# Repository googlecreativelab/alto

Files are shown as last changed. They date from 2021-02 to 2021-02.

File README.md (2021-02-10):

# Alto - a little teachable object<br>
<br>

Say hello to Alto, a little teachable object! Alto is designed to demonstrate the most basic aspects of machine learning (ML) by building a machine you can teach yourself. Alto uses the [Coral USB Accelerator](https://coral.ai/products/accelerator/) and Raspberry Pi to help show how you can easily add machine learning to your next hardware project.

This repository contains all of the instructions and files required to build an Alto of your own from scratch. Best of all, Alto is completely open source! Anyone can fork the code, schematics, and case designs to create a little teachable object of their own.

To find out more about what else you can do with the Edge TPU in the USB Accelerator, and get inspiration for your own projects, head to [Coral's Examples page](https://coral.ai/examples/).

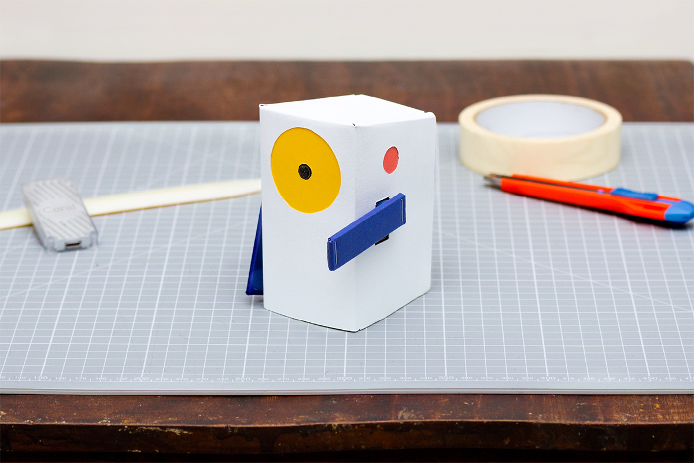
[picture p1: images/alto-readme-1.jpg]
alto hero image

<br>
<br>
## What you’ll find in this document

This document has five chapters:

-  **[User guide](#User-guide)** -
Explaining Alto’s interface and the ways Alto can be used.

-  **[Make your own Alto](#Make-your-own-Alto)** -
A visual guide to constructing your own Alto, covering setting up the software, soldering your circuitry and constructing Alto’s cardboard body.

- **[Experiment with Alto](#Experiment-with-Alto)** -
A set of simple experiments to help understand how Alto works, and how you can use Alto to introduce some of the basic concepts of machine learning to others.

- **[Remixing Alto](#Remixing-Alto-for-your-projects)** -
A brief introduction to how you can hack your Alto to look and behave differently to fit your own application.

- **[Technical overview](#Technical-Overview)** -
A more detailed overview of Alto’s software and electronics and how they function.<br>
<br>

## User guide

### Machine learning at its simplest

Alto has a camera on its front, and an arm and button on each side. Alto uses the camera to observe the world around it. The buttons are used to start learning, and Alto will point with its arm when it sees something it has learned to recognise. 

about alto animated gif<br>
<br>

Alto can learn two classes of things. When Alto recognises one of them, it will point with its corresponding arm. Alto demonstrates machine learning at its most basic level: what you teach it to recognise is up to you!

alto points at fruit<br>
<br>

### Teaching Alto

To teach Alto to recognise an object, place the object in front of it, and press one of the buttons on the side. As Alto takes images to learn about the object, its arm will slowly raise. When Alto’s arm is stretched out horizontally, the learning process has finished. Now, when the same object is placed in front of it, Alto will point at the object.

The more you teach Alto about the same object, the better it will become at recognising that thing. You can teach Alto as many times as you like! Try teaching Alto more about an object by rotating the object to show different angles and place it at various distances, pressing the same button each time.

It's important to try and balance the amount of learning that Alto does on each side. If it learns about one object 5 times, but only once about another, then it is likely to be much better at recognising the one that it has seen more often.

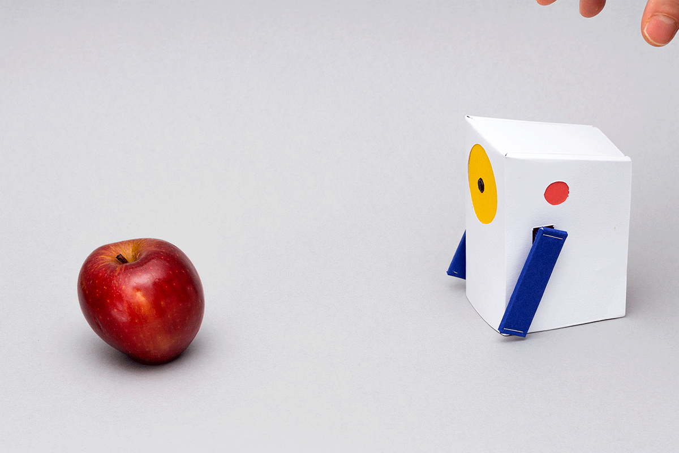
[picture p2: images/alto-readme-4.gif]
alto points at red apples

<br>
<br>
### Recognising objects

Start by teaching Alto to recognise a different object for each arm, for example, to teach Alto the difference between types of fruit, teach it about a red apple on one side, and a banana on the other. 

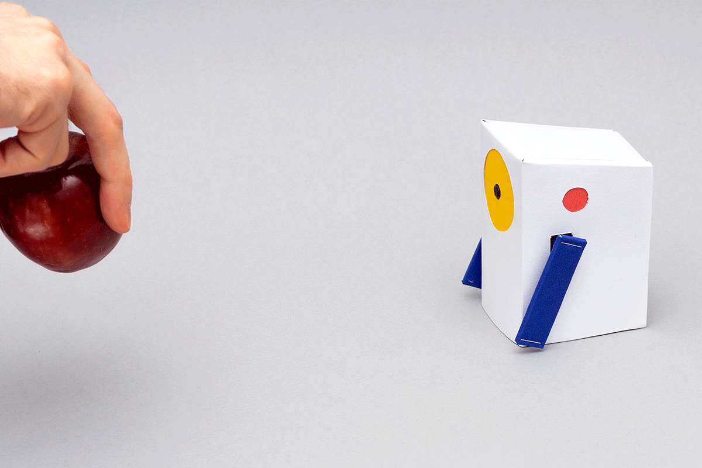
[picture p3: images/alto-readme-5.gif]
alto points at a red apple

<br>
<br>
### Recognising classes

Beyond recognising individual objects, you can teach Alto to recognise classes of objects. Building on what it has learned about red apples, could you teach it to recognise red objects in general, rather than just apples? Once Alto has learned to recognise two classes, can it correctly recognise a new red object that it hasn’t seen before?

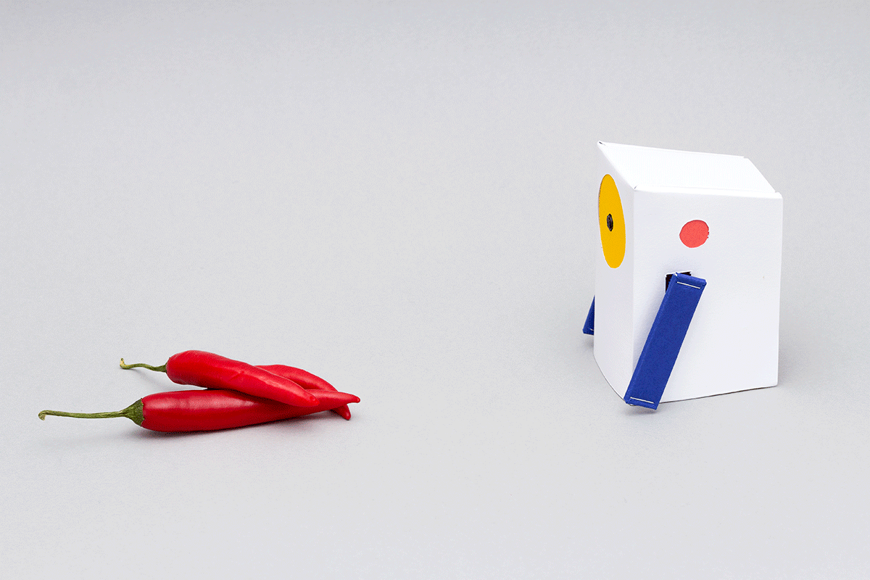
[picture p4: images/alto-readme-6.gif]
alto points at red objects

<br>
<br>
### Forgetting

If you want to teach Alto something new, you can clear its memory by holding down both buttons simultaneously for 3 seconds. This will erase everything Alto was taught on both sides, and can’t be undone.

To learn about any of these processes in more detail, take a look at the [Experiment with Alto](#experiment-with-Alto) section below.

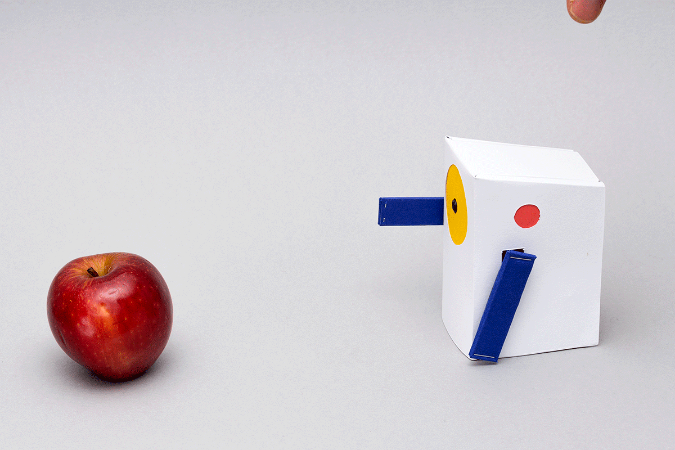
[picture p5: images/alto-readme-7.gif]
alto forgets

<br>
<br>
## Make your own Alto

The following steps will guide you through the process of assembling your own Alto: setting up the Raspberry Pi, soldering the electronics, and assembling a case to house all the components. To read a more detailed explanation of each step, click on the links in each section to go to the individual instruction pages. 

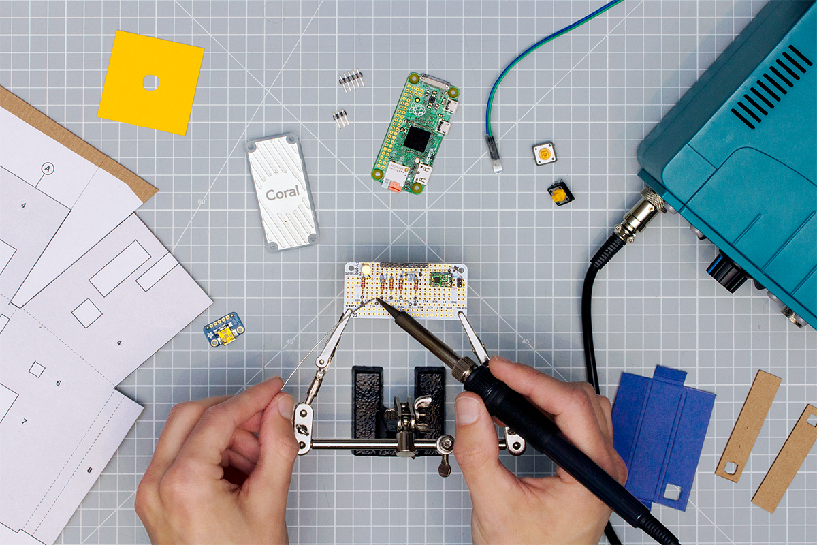
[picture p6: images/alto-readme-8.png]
soldering overhead

<br>
<br>
### 1.0: [Set up the software](1.0-Set-up-the-software.md)

The first step is to setup the software environment for Alto, and then load the Python code that makes Alto function. The Software & OS section outlines the process in full, starting with setting up the Raspberry Pi Zero, flashing the SD card and installing the Alto application software.

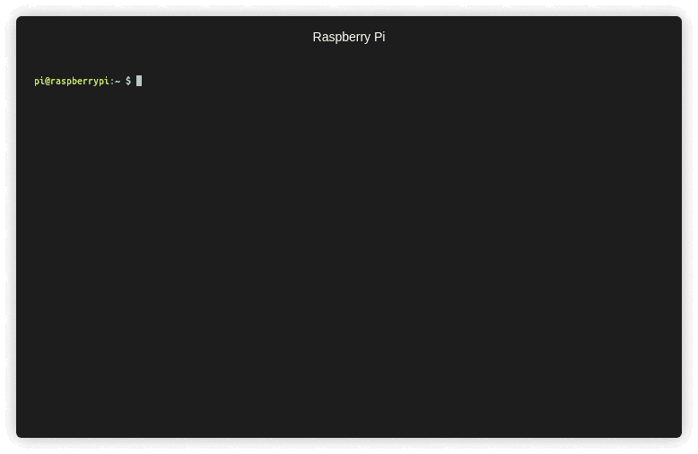
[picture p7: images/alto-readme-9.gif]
terminal output installing software

<br>
<br>
### 2.0: [Build the electronics](2.0-Build-the-electronics.md)

The electronics for Alto have been designed to be as simple and hackable as possible. You only need a few common components and basic soldering skills to assemble everything. A full step-by-step guide, with schematics and a bill of materials, is included in the Electronics directory in this repository.

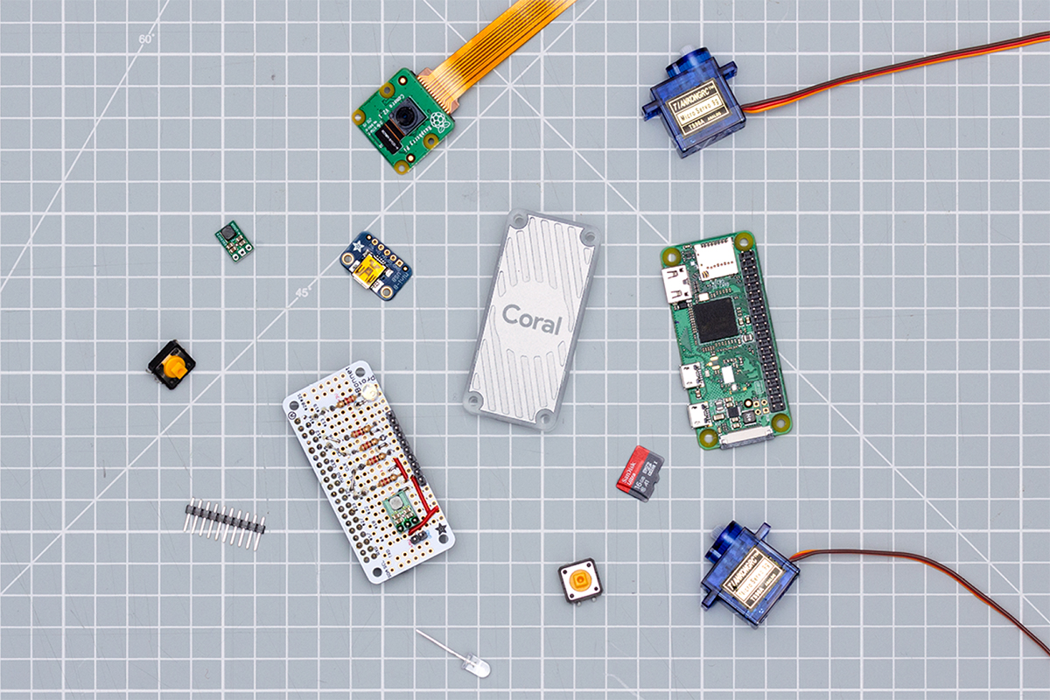
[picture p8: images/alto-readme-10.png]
overhead shot of some electronics

<br>
<br>
### 3.1: [Making the electronics casing](3.1-Making-the-electronics-casing.md)

The inner structure of Alto is made from folded cardboard, and held together with staples. All the components of Alto are held in this structure: the servos, LEDs, camera, and the internal electronics package are all mounted in the cardboard layers.

To begin, you will need to print out the [PDF template](casing/alto-paper-templates.pdf) and stick it to your materials. This will be your guide for cutting the cardboard into the correct shape. All the labels are printed on the template itself.

You can accomplish this step using hand tools (e.g. a craft knife) which will take around 45 minutes, or a laser cutter if you have access to one, which will be significantly quicker.

For more detailed instructions on this stage of constructing your Alto, refer to the [electronics casing](3.1-Making-the-electronics-casing.md) instructions.

cutting out and assembling paper parts
<br>
<br>
### 3.2: [Making Alto's outer casing](3.2-Making-altos-outer-shell.md)

The outer structure of Alto is made from card, and is designed to fit around and fold into the seams of Alto’s inner structure. The process is similar to before, outlined in full detail on the [outer](https://github.com/googlecreativelab/alto/blob/master/3.2-Making-altos-outer-shell.md) case build directory.

The white card makes up most of Alto’s outer structure, and hides some of its components and electronics. We provide printable coloured card accessories that highlight the yellow eye (camera), the red ears (buttons) and the blue arms (servo motor arms).

You can also customise the visual style at this stage to make your Alto unique!

assembling alto's casing
<br>
<br>
### 4.0: [Teach!](4.0-experiments-with-alto.md)

You should now have a completed Alto unit – the next stage is to teach it!

Grab some objects, plug Alto into a power source, and start exploring what you can teach Alto to recognise. If you need a bit of inspiration to get going, take a look at the Experimenting with Alto section below.

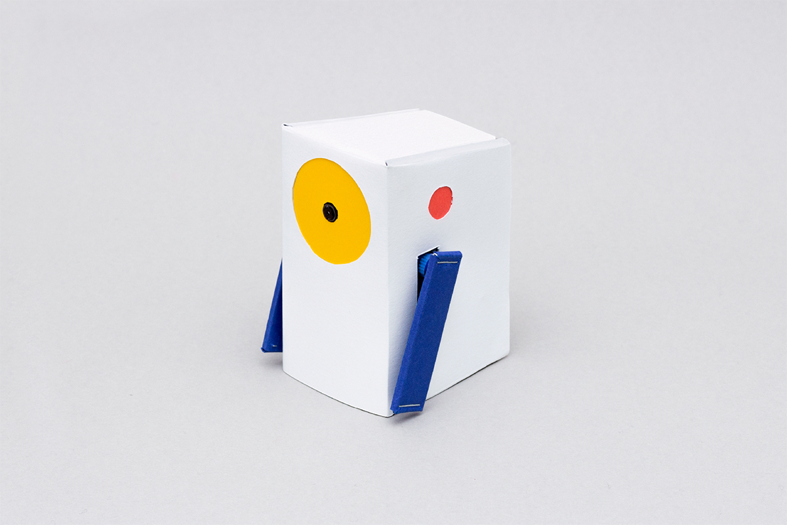
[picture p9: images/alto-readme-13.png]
alto standing alone

<br>
<br>
## [Experiment with Alto](4.0-experiments-with-alto.md)

Alto is a great way to understand the basics of machine learning. This section contains a number of experiments to help understand how Alto works, and introduce the basics of machine learning to others.

Covering aspects from simple object recognition, to introducing k-nearest neighbor (kNN) algorithms, these experiments give practical ways to bring the concepts behind Alto to life. Head to the [Experiments with Alto](4.0-experiments-with-alto.md) page to read on.

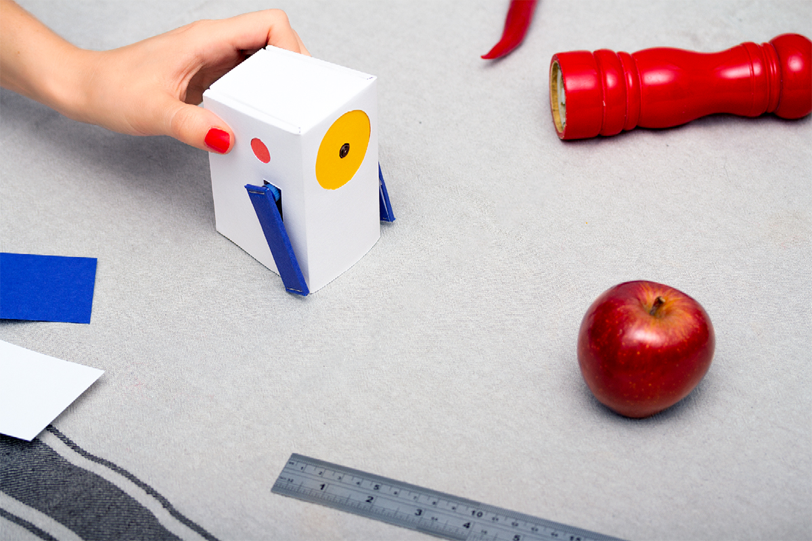
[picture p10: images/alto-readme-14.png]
alto pointed at a red apple

<br>
<br>
## [Remixing Alto for your projects](5.0-remixing-alto.md)

All the hardware and software for Alto was created with hacking and remixing in mind: the case design can be made from different materials, or refactored entirely; the electronics can be adapted to use whatever components you have available; the servos can be substituted for any type of actuator; and the software is written in a high level language (Python) that is easy to modify. 

Here are just some of the ways you can hack your own Alto:

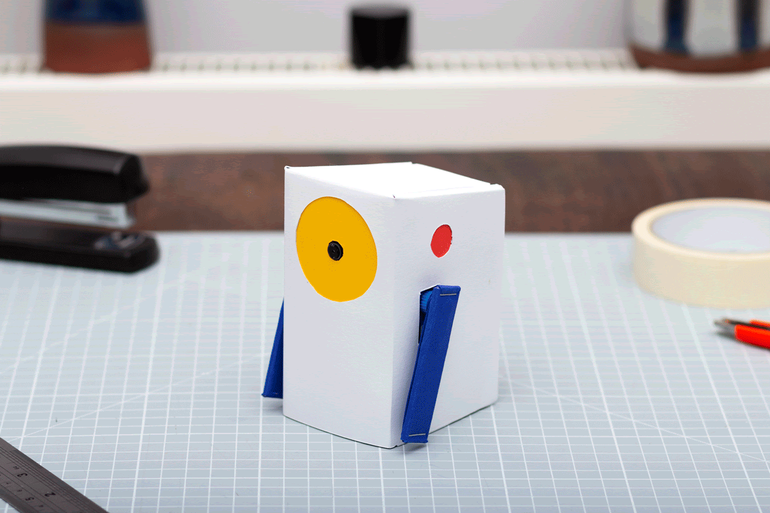
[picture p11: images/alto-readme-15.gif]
different alto form factors

<br>
<br>
### Hacking the [software](5.0-remixing-alto.md#hacking-altos-software)
Small tweaks to the existing code can be made to change Alto’s confidence level or behaviours.

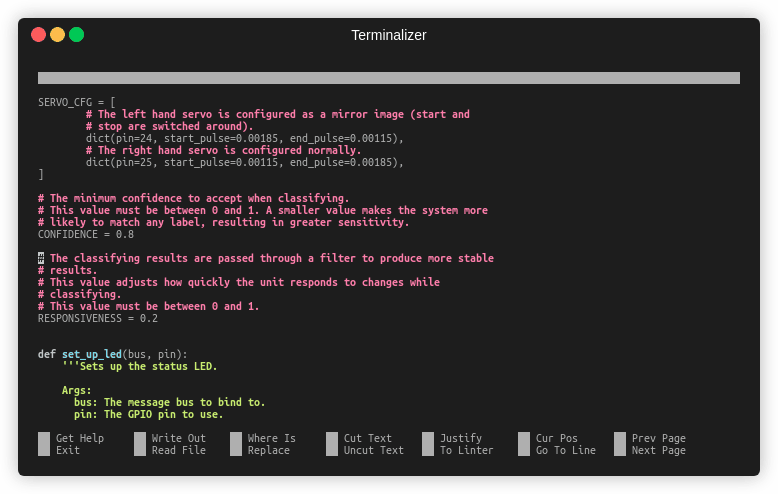
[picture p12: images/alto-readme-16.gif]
changing alto's code

<br>
<br>
### Hacking the [hardware](5.0-remixing-alto.md#hacking-altos-hardware)

Go beyond servos, to explore new ways for Alto to show its recognised something.

alto with LED confidence meter
<br>
<br>
### Hacking the [casing](5.0-remixing-alto.md#hacking-altos-casing)

The casing for Alto can easily be changed to fit whatever application you might have in mind. Whether that’s simple aesthetic changes to modify Alto’s look, or changes to the design of the arms or body that might let Alto do new things. 

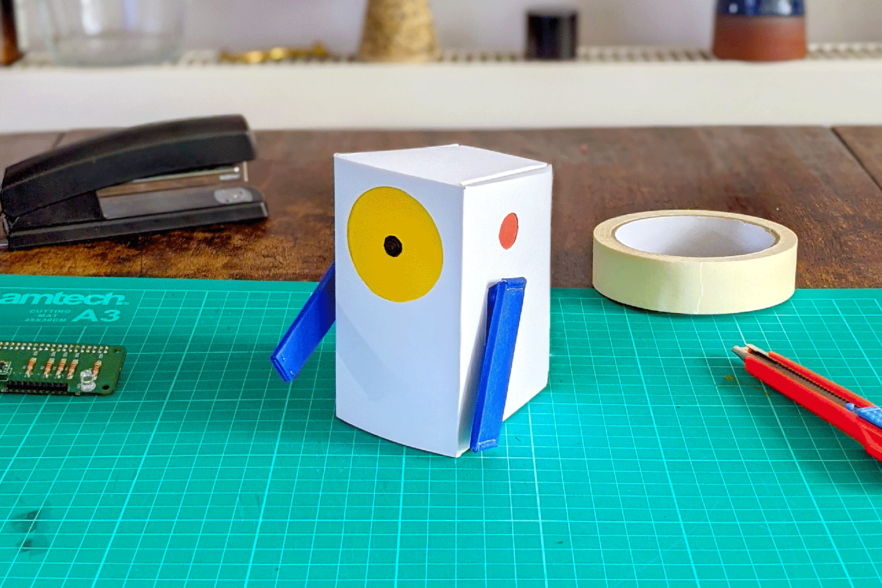
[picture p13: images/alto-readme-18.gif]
different alto form factors and designs

<br>
<br>
Hacking Alto is a great step towards building your own machine learning projects. If you come up with anything cool using the Coral USB Accelerator, show us! Submit your machine learning experiment to the Experiments with Google platform [here](https://experiments.withgoogle.com/submit).

## Technical Overview

There are three main elements to Alto: a Raspberry Pi Zero single-board computer with a camera attachment; a [Coral USB Accelerator](https://coral.ai/products/accelerator/) for accelerating on-device machine learning; and some simple electronics for its user interface.<br>
<br>

### OS & compute

The Raspberry Pi Zero runs Raspberry Pi OS. It is responsible for interfacing with the user’s connected hardware (connected via GPIO), the camera module, and the Coral Edge TPU (connected via USB). The OS starts automatically, and acts as host for the software application that runs Alto. 

The system accelerates all ML inferencing (and some of the learning) by delegating ML graph execution to the Edge TPU on the Coral USB Accelerator. The Edge TPU is a machine learning coprocessor that enables low-powered computers like the Raspberry Pi to run advanced ML workloads at a much greater level of performance than if they were run on CPU. All of the ML tasks performed by Alto are done on-device (offline) using the Edge TPU.

Although the Coral software for the Edge TPU does not officially support the Raspberry Pi Zero (because it has an ARMv6 chipset, but Coral officially requires ARMv8), the [Coral software for the Edge TPU Runtime](https://github.com/google-coral/libedgetpu) is open sourced and has been successfully [compiled for the Raspberry Pi Zero](https://github.com/google-coral/edgetpu-platforms).

You can find out more about Coral and the Edge TPU hardware on the [Coral website](https://coral.ai/products/).<br>
<br>

### Software

The Alto software application is written in Python. It receives input from the Raspberry Pi camera module, prepares it for classification by the Edge TPU module, and interfaces with the electronics interface. The application uses a k-nearest neighbor classifier model (k-NN) to identify the proximity of a given image to others in its learned dataset.

When Alto is learning, it calculates the embedding of the incoming data from the image sensor in its model and assigns it a label - in the case of Alto, this label is either its left or right arm. When Alto is in recognition mode, the embeddings of data frames from the image sensor are determined and their proximity to other known embeddings is calculated; if these are within a certain distance of a labelled embedding, then Alto has recognised something, and will point at it with its corresponding arm.<br>
<br>

### Electronics

The electronics for Alto are designed to be as flexible and hackable as possible. It is based around a single through-hole prototyping board which can be assembled easily by hand. This board connects to the GPIO pins of the Raspberry Pi Zero, and breaks out headers for the other component parts of Alto: two servos, two buttons, and one LED.

Each of these items are common and easy to get, or you might even have them in your hacking space already. Alternatively, they can easily be substituted for other parts, for example if you have different servos or LEDs available. The design and Bill of Materials (BOM) includes a prefabricated USB breakout board, which includes a discrete power regulation circuit that will ensure smooth delivery of adequate power to Alto during normal operation.

You can find more information about the electronics in the [electronics](2.0-Build-the-electronics.md) directory, and the bill of materials is available [here](electronics/alto-bom.xlsx) as a downloadable spreadsheet.<br>
<br>

## Notes

This is a collaborative effort between Google Creative Lab and our partners at [RRD Labs](https://github.com/dgym). This is not an official Google product.

We encourage open sourcing projects as a way of learning from each other. Please respect our and other creators’ rights, including copyright and trademark rights when present when sharing these works and creating derivative work. If you want more info on Google's policy, you can find it [here](https://www.google.com/permissions/). To contribute to the project, please refer to the [contributing](CONTRIBUTING.md) document in this repository.

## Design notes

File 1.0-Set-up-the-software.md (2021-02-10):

# 1.0 Set up the software <br>
<br>

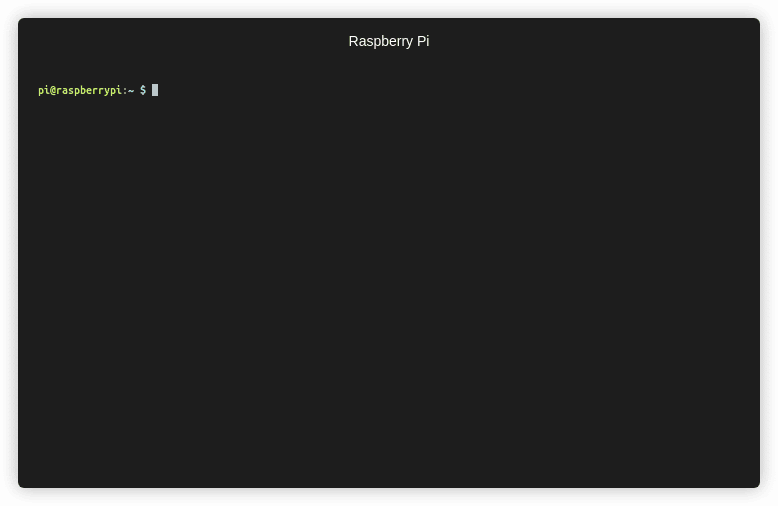
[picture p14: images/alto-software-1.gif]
setting up alto's software
<br>
<br>

This directory contains the source files for the application software that runs Alto. If you are building an Alto for the first time, you should use the downloadable software image, which comes fully configured out of the box. 

If you don’t want to make changes to Alto’s behaviour, then you can just use the first section of these instructions (['Using the SD card image](#using-the-sd-card-image-recommended))’). The other sections in this readme cover how to configure the OS, install the application software, and make changes to Alto’s behaviour in a little more detail.

**Skills required**
- Basic terminal commands

**Time to complete**
- 10 mins

**Things you’ll need**
- SD card image file ([download here](https://storage.cloud.google.com/experiments-uploads/alto_2021.bz2))
- microSD card (at least 8 GB capacity)
- Card reader
- Optional: wired keyboard and screen to connect to Raspberry Pi<br>
<br>

## Using the SD card image (recommended)

The supplied SD card image contains all the software needed to run Alto. It’s fully configured and ready to work out of the box—you just need to flash it to an SD card, insert it into the Raspberry Pi, and you’re ready to go! There are a couple of ways you can flash the SD card: using a GUI application, or using the terminal on your computer.<br>
<br>

### Flashing the SD card with a GUI tool

A GUI tool will give you a visual guide for flashing your SD card. The tool you need to use depends on the type of computer you have, as there are different tools for different platforms; a few examples include:

- [Raspberry Pi Imager](https://www.raspberrypi.org/software/)
- Etcher (Mac, Linux, Windows)
- Win32 Disk Imager (Windows)
- SD Card Association formatter (Mac & Windows)

You can find alternative applications and instructions for using each of these tools by searching the web. Note that the disk image itself is compressed to make downloading it easier, and you’ll need to uncompress it before flashing to the SD card.<br>
<br>

### Flashing the SD card using Terminal on your Mac

If you are using a Mac computer, you can use applications that run in your Terminal to write the image to the SD card. (These instructions will translate very closely to Linux and other Unix systems too, but you will need to research the specific commands for your system.)

1. Start by opening a Terminal session (Applications → Utilities → Terminal)

2. Navigate to the location you downloaded the disk image using the ```cd``` command, for example:
```
$ cd ~/Downloads/
```

3. Insert the SD card into your card reader, and use the ```diskutil list``` command to list the disks attached to your computer. 
```
 /dev/disk2 (external, physical):
#:         TYPE NAME                SIZE        IDENTIFIER
0:         FDisk_partition_scheme   *15.9 GB    disk2
1:         Windows_FAT_32 boot      45.0 MB     disk2s1
2:         Linux rootfs             15.9 GB     disk2s2
```

4. In the output of this command, look for the block that relates to your SD card (you can usually spot it from the size of the disk). You need to look for the ```IDENTIFIER``` for your disk. In the example above, our 16GB SD card is identified as ```disk2```

5. Use ```diskutil``` to unmount the disk, for example:
```
$ diskutil unmountDisk disk2
```

6. The disk is now unmounted, and we are ready to write the image to it. We can use the tools ```bzcat``` and ```dd``` to uncompress and write the image on the fly, respectively. Enter the following command to start writing the disk, inserting the image filename you downloaded and the ```IDENTIFIER``` of your disk (note that for a speed boost, you can add an ```r``` to the ```IDENTIFIER```, for example ```disk2``` becomes ```rdisk2```:
```
$ bzcat <IMAGE NAME> | sudo dd of=/dev/<IDENTIFIER>
```

For example, with the downloaded filename ```image.img.bz2``` and the ```IDENTIFIER``` as ```disk2```:
```
$ bzcat image.img.bz2 | sudo dd of=/dev/rdisk2 bs=32m
```

7. The time it takes to write the SD card image will depend on the speed of your card and the speed of the reader, but it will typically take between 10 and 20 minutes. When the writing has completed (when the terminal prompt is returned to you), you should use ```diskutil``` to eject the disk before removing it from your computer:
```
$ diskutil eject disk2
```
<br>

### Testing

Before proceeding to the next section, you should verify that your SD card has written correctly. To do this, insert it into the Raspberry Pi, connect a keyboard, screen, and the USB Accelerator, and connect the Pi to a USB power source. On its first boot, it may take a few minutes to verify the filesystem before a terminal appears on screen. After the filesystem check is complete, you should see a terminal on screen. Log in with the default username / password (pi / raspberry), then shut the system down by entering the ```poweroff``` command:
```
$ sudo poweroff
```
<br>

## Setting up from scratch (advanced)

It’s recommended to use the SD card image if you are setting up Alto for the first time, especially if you are not making any changes to its behaviour. This guide is included to give you an overview of the technical underpinnings of Alto which you can refer to if you wish to modify its code.<br>
<br>

### About the system

At Alto’s heart is a Raspberry Pi Zero and the Edge TPU in the Coral USB Accelerator. The Raspberry Pi Zero runs Raspberry Pi OS. It’s responsible for interfacing with the user’s connected hardware (connected via GPIO), the camera module, and the Edge TPU (connected via USB). The OS starts automatically, and acts as host for the software application that runs Alto.

The system accelerates all ML inferencing (and some of the learning) by delegating ML graph execution to the Edge TPU on the Coral USB Accelerator. The Edge TPU is a machine learning coprocessor that enables low-powered computers like the Raspberry Pi to run advanced ML workloads at a much greater level of performance than if they were run on CPU. All of the ML tasks performed by Alto are done on-device (offline) using the Edge TPU. You can find out more about Coral and the Edge TPU hardware on the [Coral website](https://coral.ai/products/).<br>
<br>

### OS & dependecies

The Raspberry Pi that runs Alto runs on Linux (the example SD card uses Raspbian Stretch Lite); you will need to get an installation image for your chosen OS from the web.<br>
<br>

#### Install using the setup script

This repository contains a setup script which will install all required dependencies and configure the OS to start the Alto software at launch. To use this script, log in to your system and either clone or copy the repo to the device. Change to the ```linux``` directory and run the script:
```
$ cd linux
$ sudo ./setup.sh
```

#### Install manually

1. From a freshly flashed image, install the OS dependencies
```
$ sudo apt-get update
$ sudo apt-get install -y git python3-picamera python3-pigpio python3-rpi.gpio
```

2. Enable the camera
```
$ sudo raspi-config
```

3. To reduce CPU usage, it’s recommended to edit ```/lib/systemd/system/pigpiod.service``` and append ```-s 10``` to the ```ExecStart``` line.

4. Enable ```pigpiod```
```
$ sudo systemctl enable pigpiod
$ sudo systemctl start pigpiod
```

5. Install the EdgeTPU Runtime and Python API
```
$ wget --content-disposition https://github.com/google-coral/edgetpu-platforms/releases/download/v1.9.2/edgetpu_api_1.9.2.tar.gz
$ tar xvf edgetpu_api_1.9.2.tar.gz
$ cd edgetpu_api
$ sudo bash install.sh
$ cd ..
```

6. Clone the Alto repository
```
$ mkdir ~/code
$ cd ~/code
$ git clone https://TODO Alto
```

7. Run the app
```
$ cd ~/code/Alto/app
$ python3 Alto.py
```

## :tada: Woohoo! You've finished this section :tada:

## Next section &#8594; [2.0: Build the electronics](2.0-Build-the-electronics.md)

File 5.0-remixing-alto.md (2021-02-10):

# Bonus: Remixing Alto<br>
<br>

Alto has been designed specifically with hacking and remixing in mind. There are countless ways to personalise your Alto; from simple visual tweaks, to complete component overhauls. This guide briefly shows some of the ways you might want to remix your Alto, but don’t stop there. Explore the examples and find completely new ways to remix Alto for your projects.

## Hacking Alto's software

With Alto’s code being written in Python, it's easy to add or change how Alto behaves. There are countless tweaks you might want to make to Alto’s code for your own projects - one might be to adjust Alto’s confidence value which controls if Alto makes a classification or not.



The value controlling Alto’s confidence is CONFIDENCE which can be found in the [alto.py](app/alto.py) file. This variable can be set to any float value between 0 and 1, with higher values requiring Alto to be more confident about a classification and pointing its arm.

Of course this is just the start of what can be done. Get creative and explore how altering the code can change how Alto responds when it recognises something. Many Python tutorials are available online to help get you started.<br>
<br>

## Hacking Alto's hardware

Alto’s arms not giving you the output you need? No problem! Using the GPIO pins on the Raspberry Pi and coding in Python, it’s easy to completely change the components used to give Alto completely new forms of expression.

In this example, we’ve added an LED ring to Alto’s front face and programmed it to illustrate Alto’s confidence score when evaluating objects. 



Get creative with output components for Alto. Remember that whenever you change components, you should make sure you have an adequate power supply and any additional control circuitry you might need. With new hardware, you might also need to redesign your card casing.<br>
<br>

## Hacking Alto's casing
The most straightforward way to remix Alto for your own projects is to modify the casing design.

Try new colours and materials for Alto’s outer casing that work for you and your project. Here are a few of our favourite examples of how people have given Alto radically different looks:

<br>
<br>

If you want to go further, you can even re-design the cardboard nets to change the shape of Alto. By editing the .ai file, you can adjust the size and shape of Alto to fit any application.

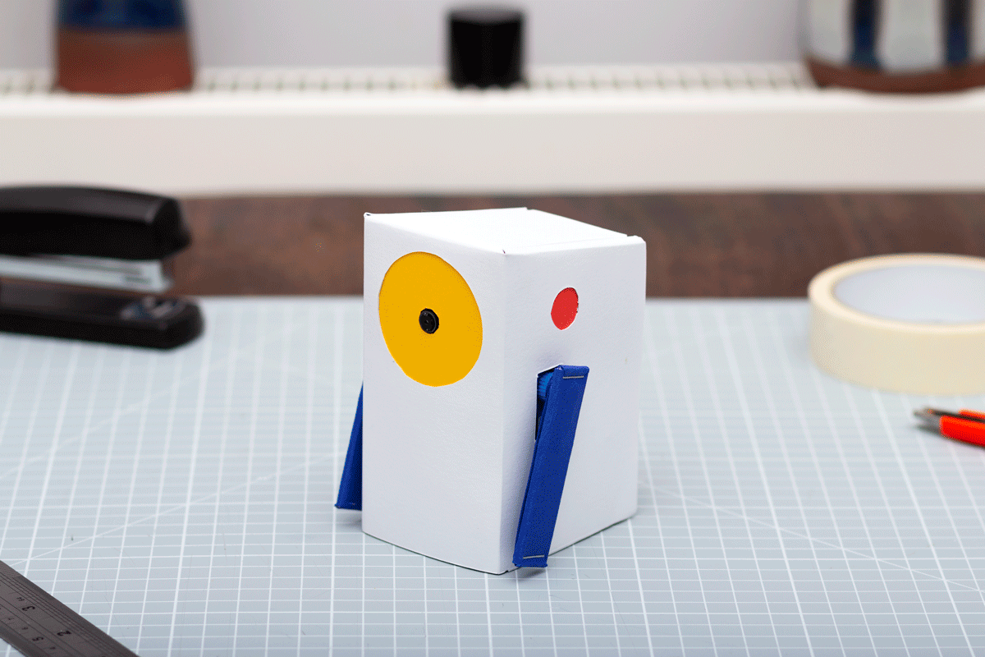
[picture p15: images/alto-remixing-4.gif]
<br>
<br>

If you have access to other fabrication tools, try exploring different processes and materials for Alto’s casing. Small elements like Alto’s arms can easily be 3D printed to add new functionality, or you can even design a whole new body for Alto. You can download the 3D files we experimented with for alternative arms [here](extras/alt_alto_arms.stl).



<br>
<br>

These are just some of the ways you can hack Alto. If you come up with anything cool, share it online to inspire others.

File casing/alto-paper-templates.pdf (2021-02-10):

A1

4

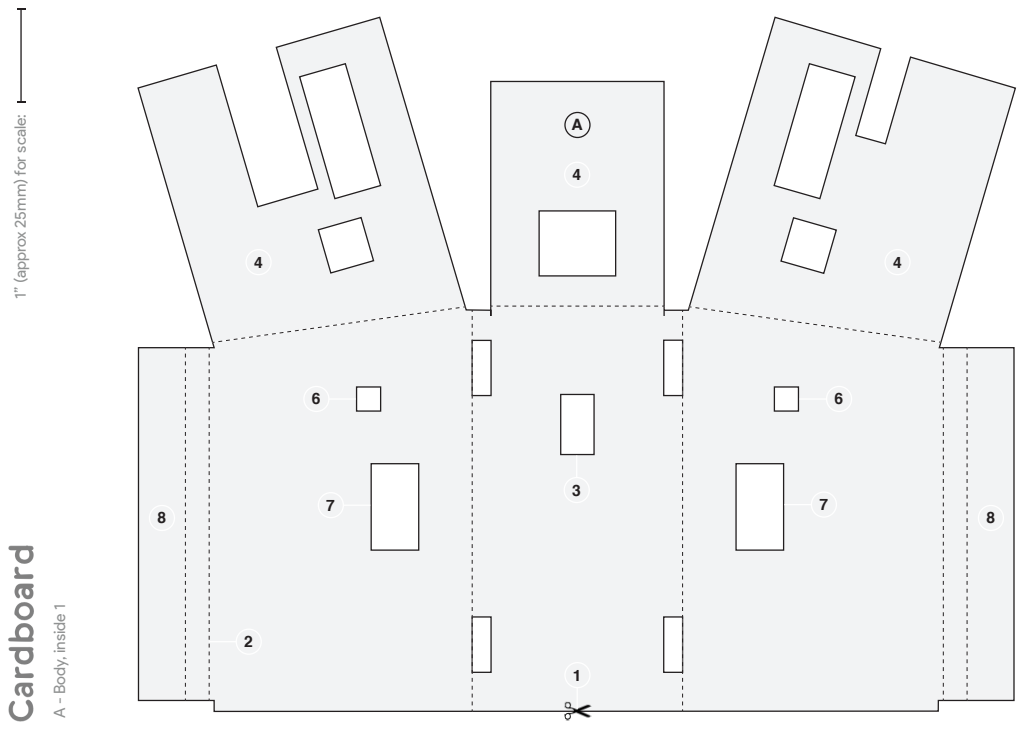
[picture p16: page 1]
A - Body, inside 1

1” (approx 25mm) for scale:

C

13 13

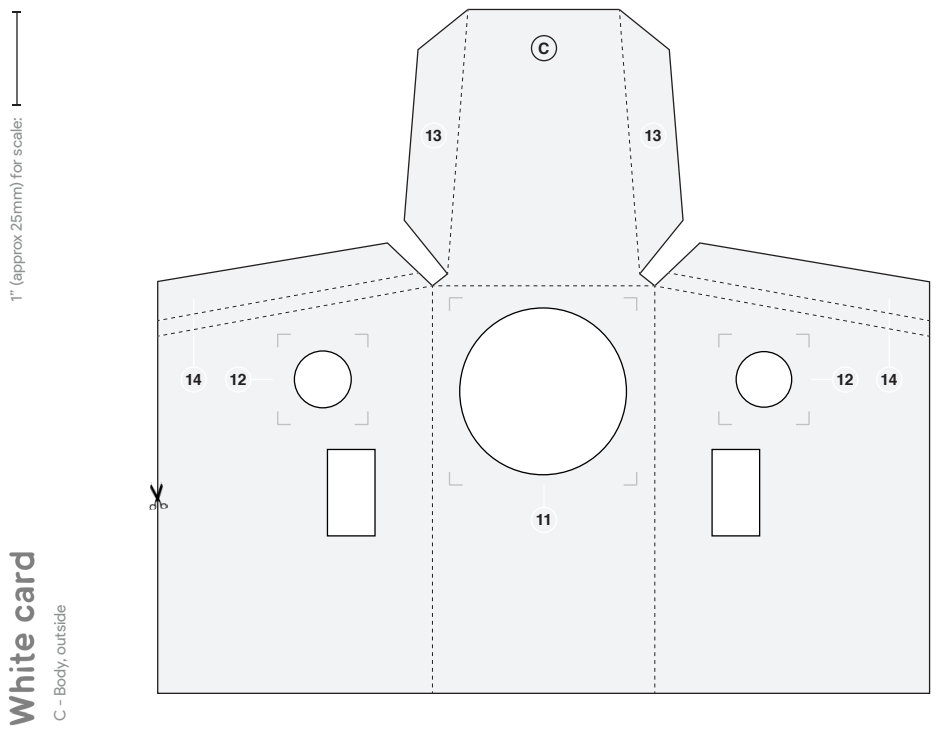
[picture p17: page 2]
C - Body, outside

1” (approx 25mm) for scale:

1” (approx 25mm) for scale:

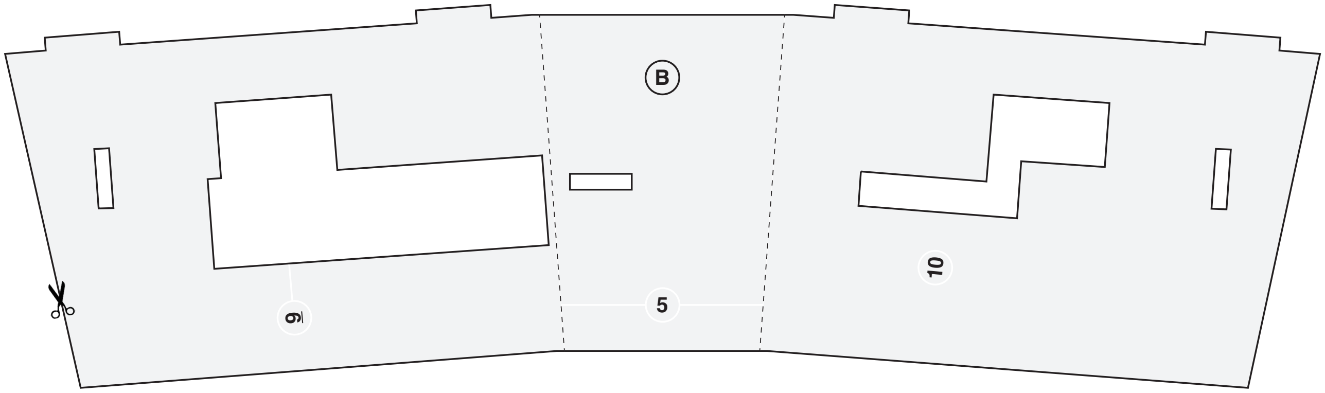
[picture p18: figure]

B - Body, inside 2
G - Arms, inside
G | 15 | 15

G

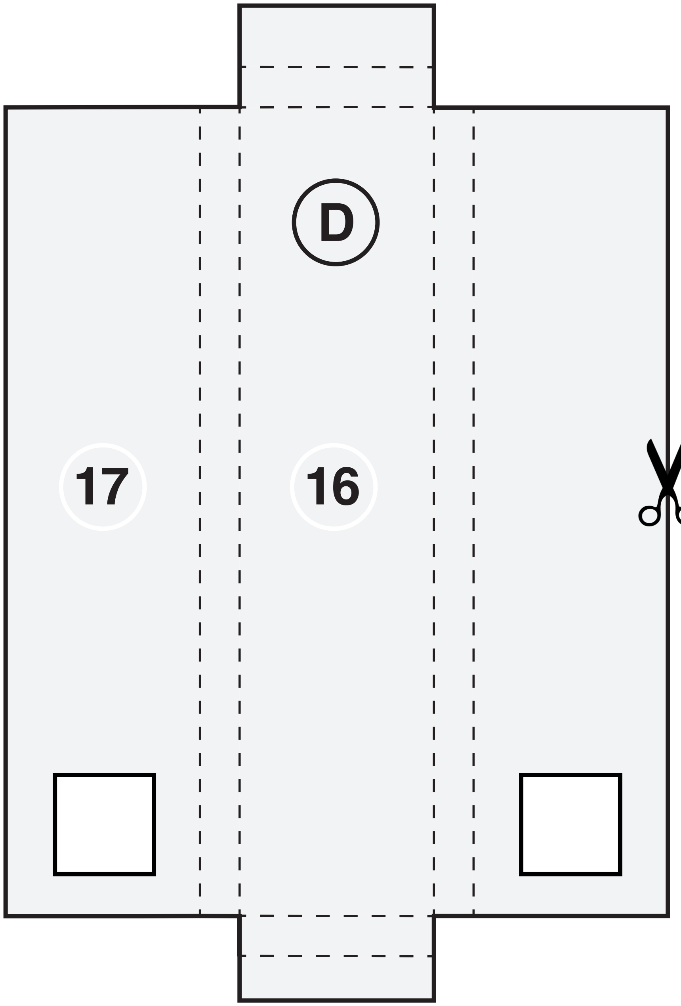
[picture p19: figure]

E - Eye

F - Ears

D - Arms, outside

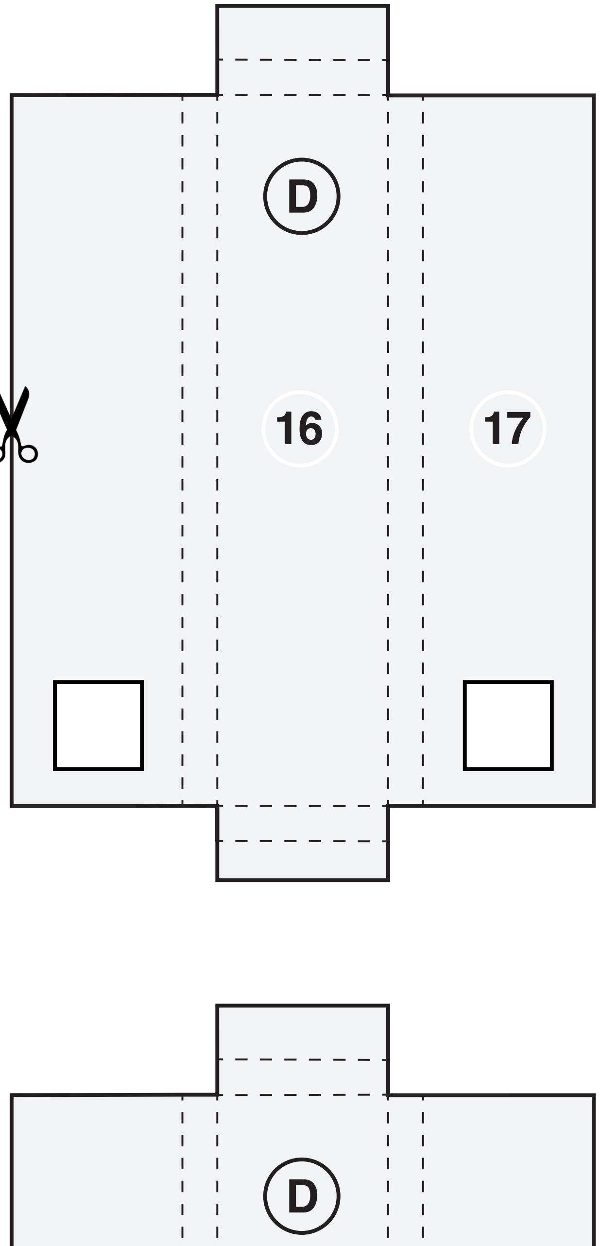
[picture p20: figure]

E

FF

1” (approx 25mm) for scale:

## alto - a little teachable object

Parts required
You will need the following tools and materials to build your own teachable object:

Paper stuff
-2mm Cardboard (flute E)*
-White card (300 gsm)
-Coloured card (blue, red, yellow)

Tools
-Craft knife
-Stapler
-Metal rule
-Glue stick
-Bone folder (or a coin)

*Note: the templates have been designed with this size and type of cardboard -different sizes might affect the fit of some of the electronics.

Printing
Print these pages at 100% scale on A4 paper, making sure they aren’t ‘scaled to fit’.

1”:

3cm:

Cutting
Using a craft knife, carefully cut out all the templates. When cutting the cardboard, score lightly along the line first, and then do a second pass with the knife, to cut all the way through.

Try to cut along the centre of these thicker black lines:

Scoring & Folding
All fold lines are indicated with a dashed line, that looks like this:

Use a bone folder to initially crease the fold lines - or you can use most pointy blunt objects for scoring, like the edge of a coin.

While scoring you ideally want to squish the cardboard layers, making sure you don’t pierce the layers. Each score line should leave an indent, but not break the surface.

Then pre-fold along the fold lines to make the assembly easier later.

To read our full instructions on how to set up the software, assemble the electronic components, and build the casing, head to github.com/googlecreativelab/alto.

## Learns

by pressing one
of the buttons

Recognises and lifts arm

to point

## Forgets

when you press both
buttons for 3 seconds

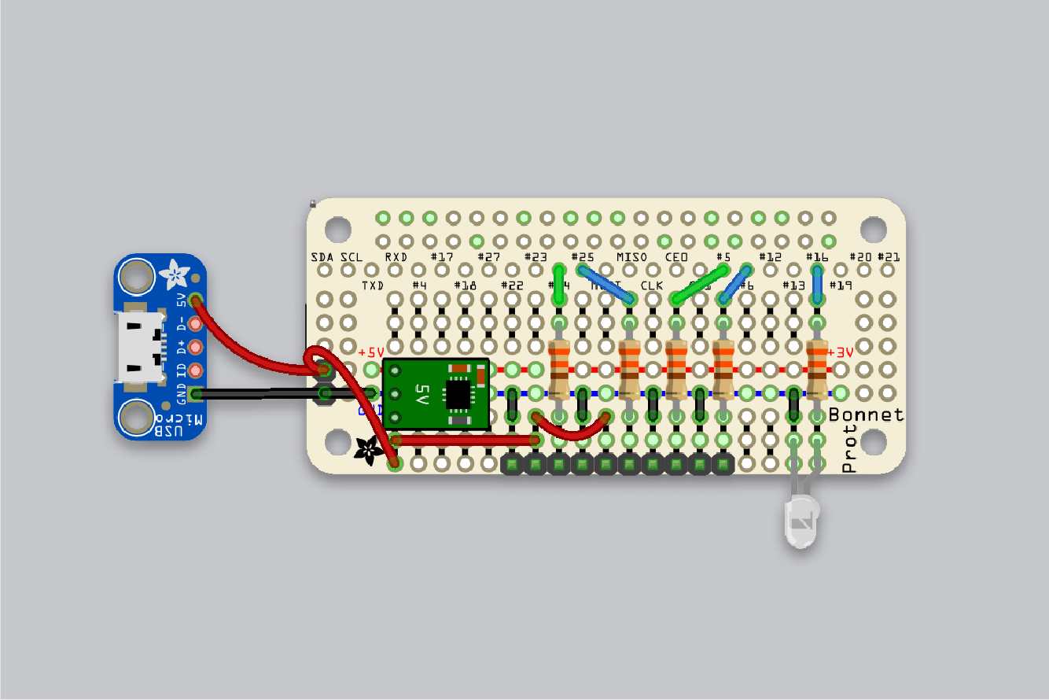
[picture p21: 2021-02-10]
electronics/alto-proto-bonnet-unannotated.png

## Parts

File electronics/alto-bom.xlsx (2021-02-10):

Please note, this spreadsheet contains information on, and links to, the components we used to build Alto originally. The links are by way of suggestion only and are not intended as any endorsement or recommendation to use these particular suppliers. Depending on your location, availability of suppliers, and date accessing this, some of these components may not be available to you, and may have changed price. If a component specified here is not available, try sourcing a suitable alternative with similar electrical and physical properties. Be aware, when using alternative components, you might have to make some adjustments to the supplied design.
Protoboard Parts
Component | Image | Part Number | Quantity | US Supplier | Price ($) | UK Supplier | Price (£) | Notes
Adafruit Perma Proto Bonnet Mini Kit |  | 3203 | 1 | https://www.adafruit.com/product/3203 | $4.50 | https://thepihut.com/products/adafruit-perma-proto-bonnet-mini-kit | £4.00
Hookup wire |  | 1311 | 1 pack | https://www.adafruit.com/product/1311 | $15.95 | https://thepihut.com/products/hook-up-wire-spool-set-22awg-stranded-core-6-x-25ft | £18.50
PCB Parts
Component | Image | Part Number | Quantity | US Supplier | Price ($) | UK Supplier | Price (£) | Notes
PCB |  |  | 1 |  |  |  |  | This PCB is a custom part made to order. Please refer to the Github Repo to download the gerber files for fabrication
2x20 way socket strip, 0.1 inch (2.54mm) pitch |  | 4079 | 1 | https://www.adafruit.com/product/4079 | $1.95 | https://thepihut.com/products/2x20-socket-riser-header-for-raspberry-pi-hats-and-bonnets | £2.00
Common parts for both Protoboard and PCB builds
Component | Image | Part Number | Quantity | US Supplier | Price ($) | UK Supplier | Price (£) | Notes
Polulu 5V step up step down regulator |  | S9V11F5 | 1 | https://www.pololu.com/product/2836 | $5.95 | https://coolcomponents.co.uk/products/5v-step-up-step-down-voltage-regulator-s9v11f5 | £5.41
220 or 330 Ohm 1/4W through hole resistors |  | 2780 | 1 pack | https://www.adafruit.com/product/2780 | $0.75 | https://coolcomponents.co.uk/collections/passive-components/products/resistors-10-pack?variant=31496785264701 | £1.20
Straight pin header, 0.1 inch (2.54mm) pitch, 20-40 pins |  | 392 | at least 16 pins | https://www.adafruit.com/product/392 | $4.95 | https://thepihut.com/products/break-away-0-1-36-pin-strip-male-header-black-10-pack | £4.50
White LED |  | 754 | at least 1 | https://www.adafruit.com/product/754 | $6.95 | https://thepihut.com/products/ultra-bright-led-5mm-white-10-pack | £1.50 | Any alternative LEDs with a similar power consumption can be used
USB Micro-B Breakout Board |  | 1833 | 1 | https://www.adafruit.com/product/1833 | $1.50 | https://thepihut.com/products/adafruit-usb-micro-b-breakout-board | £1.50 | Alternative USB connector types can be used depending on what cables you have
Female/Female Jumper Wires |  | 1951 | 1 pack | https://www.adafruit.com/product/1951 | $1.95 | https://thepihut.com/products/premium-female-female-jumper-wires-40-x-6 | £3.50
Raspberry Pi Zero WH |  | 3708 | 1 | https://www.adafruit.com/product/3708 | $14.00 | https://thepihut.com/products/raspberry-pi-zero-wh-with-pre-soldered-header | £13.50
Coral USB Accelerator |  |  | 1 | https://coral.ai/products/accelerator | $59.99 | https://thepihut.com/products/coral-usb-accelerator | £59.00
Right angle USB micro B to type C cable |  |  | 1 |  |  | https://www.amazon.co.uk/Type-Micro-Cable-Degree-Extension/dp/B07DMY3D4Z/ref=sr_1_12 | £7.99 | If you're having trouble sourcing this component, it is possible to convert a USB C cable with this connector. However, this requires delicate soldering and is not reccomended. (https://www.adafruit.com/product/1826)
Raspberry Pi Camera |  | 3099 | 1 | https://www.adafruit.com/product/3099 | $29.95 | https://thepihut.com/products/raspberry-pi-camera-module | £24.00
Raspberry Pi Zero v1.3 Camera Cable |  | 3157 | 1 | https://www.adafruit.com/product/3157 | $5.95 | https://thepihut.com/products/raspberry-pi-zero-camera-adapter | £4.00
Micro SD Card (>8GB) |  | 1294 | 1 | https://www.adafruit.com/product/1294 | $9.95 | https://thepihut.com/products/sd-microsd-memory-card-8-gb-sdhc | £9.00
SG92R Micro Servos |  | 169 | 2 | https://www.adafruit.com/product/169 | $5.95 | https://thepihut.com/products/micro-servo | £5.50
Momentary tactile push buttons |  | 1009 | at least 2 buttons | https://www.adafruit.com/product/1009 | $5.95 | https://thepihut.com/products/colorful-round-tactile-button-switch-assortment-15-pack | £5.50
USB Serial Adaptor |  | 3309 | 1 | https://www.adafruit.com/product/3309 | $5.95 | https://thepihut.com/products/adafruit-cp2104-friend-usb-to-serial-converter | £5.50
Craft Materials
Component | Image | Part Number | Quantity | US Supplier | Price ($) | UK Supplier | Price (£) | Notes
2mm Cardboard (Flute E) |  |  | at least 3 A4 sheets | https://www.amazon.com/dp/B088M38SZ3/ | $16.99 | https://modelshop.co.uk/Shop/Item/Card-corrugated-sandwich-3-5mm/ITM6524 | £1.85 per sheet | Available at most good craft stores. We have used single corrigated Flute E card (approx. 2mm thick). Alternative thicknesses can be used, but will require alterations to the casing design
White card |  |  | at least 4 A4 sheets | https://www.amazon.com/Accent-188179R-Opaque-Thick-Cardstock/dp/B0114MUOOO | $16.54 | https://www.amazon.co.uk/House-Card-Paper-300-gsm/dp/B01G6H86P6 | £5.99 | For Alto's outer casing. We used 300gsm matt card, but any A4 card or paper can be used as an alternative.
Coloured card |  |  | at least 3 A4 sheets | https://www.amazon.com/Yeesun-Coloured-Construction-Assorted-Decoration/dp/B08B5S98NZ/ | $9.99 | https://www.amazon.co.uk/Coloured-Card-A4-Asst-10/dp/B0027IUILY?th=1&psc=1 | £2.25 | We used colored card to highlight Alto's arms, buttons and camera. This is optional, and any card can be used as an alternative
Tools
Component | Image | Part Number | Quantity | US Supplier | Price ($) | UK Supplier | Price (£) | Notes
Metal Rule |  |  | 1 | https://www.amazon.com/Folding-Guard-Use-Stanley-Leather-Quilting/dp/B01HI8U6TQ | $16.99 | https://www.amazon.co.uk/Guard-Centimetres-Quilting-Imperial-Global-Ltd/dp/B01HI8U6TQ | £12.99 | For best results, use a steel ruler. A safety ruler is reccomended when using with a craft knife.
Craft knife |  |  | 1 | https://www.amazon.com/X-Acto-XZ3601-X-ACTO-Knife-Safety/dp/B005KRSWM6/ | $6.99 | https://www.amazon.co.uk/Blue-Spot-Soft-Precision-Knife/dp/B002HMRUWA/ | £5.40
Stapler and staples |  |  | 1 | https://www.amazon.com/AmazonBasics-Stapler-1000-Staples-Black/dp/B079ZV4V3C/ | $6.49 | https://www.amazon.co.uk/Rexel-Meteor-Stapler-Capacity-2100019/dp/B000SHUYOC/ | £5.40
Cutting matt |  |  | 1 | https://www.amazon.com/ASTONBAY-Double-Sided-Quilting-Crafting-Painting/dp/B08BNVQ93N/ | $12.99 | https://www.amazon.co.uk/Amtech-S0518-Cutting-Mat-A3/dp/B001IOZUHK/ | £5.99
Glue stick |  |  | 1 | https://www.amazon.com/Avery-Washable-Nontoxic-Permanent-00161/dp/B000BQPA8U/ | $1.49 | https://www.amazon.co.uk/Pritt-Stick-Standard-10g-1478529/dp/B001P3W8YC/ | £1.69
Paper printer |  |  | 1 |  |  |  |  | You will need a printer to print out the paper templates for your Alto case. Any printer capable of printing A4 paper size or larger can be used.
Bone folder (optional) |  |  | 1 | https://www.amazon.com/VENCINK-Creasing-Scrapbooking-Burnishing-Bookbinding/dp/B01MT6U2OO | $6.69 | https://www.amazon.co.uk/Genuine-Scoring-Creasing-Crafting-Scrapbooking/dp/B07ZZ1WHWJ/ | £8.49 | Bone folders help produce crisp folds in your paper and card. However, its possible to acheive the same effect using other narrow blunt objects like keys or coins

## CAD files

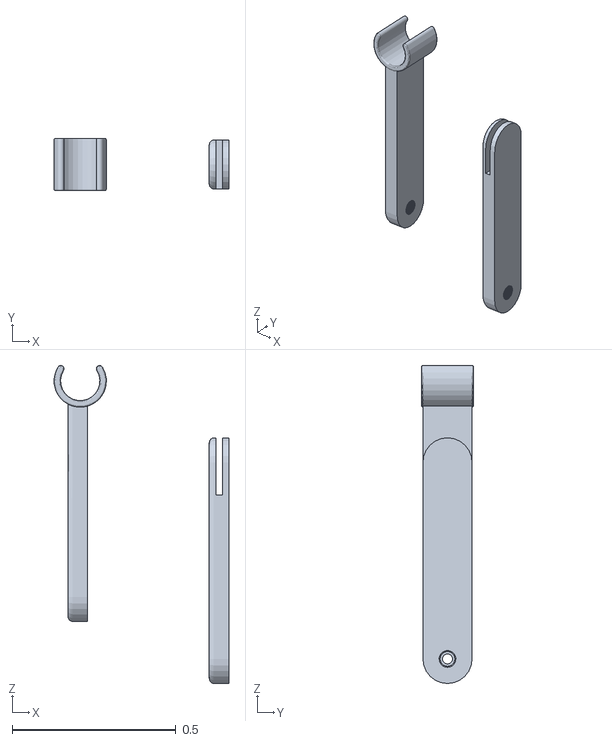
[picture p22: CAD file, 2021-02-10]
extras/alt_alto_arms.stl
0.534 x 0.16 x 0.971

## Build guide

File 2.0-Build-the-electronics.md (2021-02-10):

# 2.0 Build the electronics
<br>

This directory contains all of the source files needed to assemble the electronics for Alto. They are based around a single through-hole prototyping board which can be assembled easily by hand. This board connects to the GPIO pins of the Raspberry Pi Zero, and breaks out headers for the other component parts of Alto: two servos, two buttons, and an LED.

Each of these items are common and easy to get, or you might even have them in your making space already. Alternatively, they can easily be substituted for other parts, for example if you have different servos or LEDs available. 

The full list of components is available [here](electronics/alto-bom.xlsx) as a downloadable spreadsheet.

**Skills required**   
- Through hole soldering, reading a circuit diagram

**Time to complete**     
- 30-90 minutes (depending on your soldering experience)

**Tools you’ll need**     
- Soldering iron
- Solder 
- Wire strippers
- Optional: helping hand, solder tip cleaner, multimeter, heat proof mat<br>
<br>

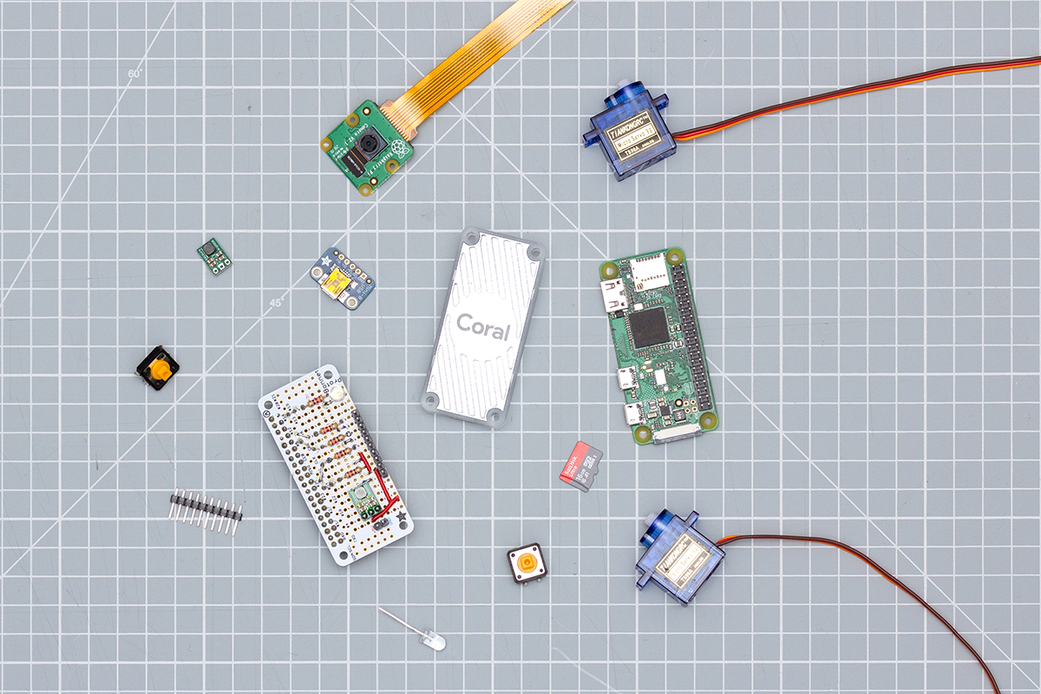
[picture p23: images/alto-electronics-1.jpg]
<br>
<br>

## Two approaches

There are two approaches to creating the electronics for Alto: 
1. using a protoboard 
2. using PCBs

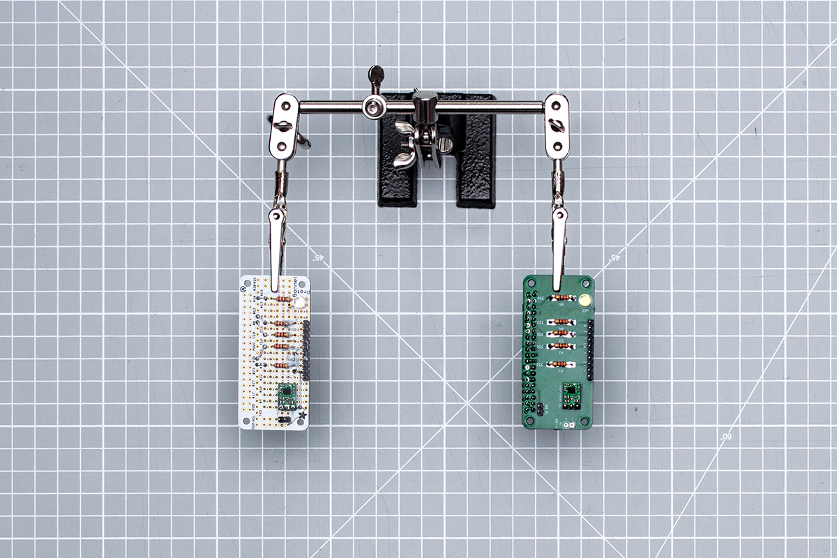
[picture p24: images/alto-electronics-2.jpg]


If you're only building one or two Altos, hand assembly with a protoboard is probably the simplest way to approach the construction. If you are assembling more than a couple of units, you may wish to consider getting some PCBs created.

Either approach will use the same set of components that are listed in the [bill of materials](electronics/alto-bom.xlsx) (BOM) spreadsheet.<br>
<br>

### Option 1: Protoboard

The simplest approach to constructing an Alto unit is to use protoboard. All of the components used are through-hole and easily soldered by hand. The remote components (buttons and servos) are connected to headers on the protoboard, which itself is connected to the GPIO header on the Raspberry Pi Zero.

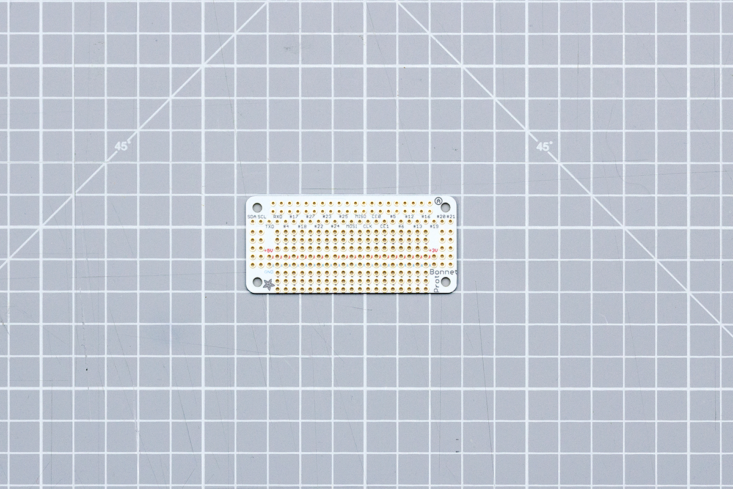
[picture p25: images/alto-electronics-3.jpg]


The image below shows the different connectors and functionality of the protoboard:

- (A) Servo connectors – six header pins for connecting the two servos that control Alto‘s arms
- (B) Button connectors - four header pins for connecting the left and right side buttons
- (C) GPIO header - here you will need to solder on a 40 pin female header connector to connect your protoboard to the Raspberry Pi Zero’s GPIO male header
- (D) Status LED - a single LED which can be used for debugging your Alto build
- (E) Power input - two pin header for connecting power
- (F) Power regulator - a discrete subcircuit for ensuring smooth power delivery to the Raspberry Pi Zero
- (G) Resistors - current limiting resistors to protect the GPIO pins

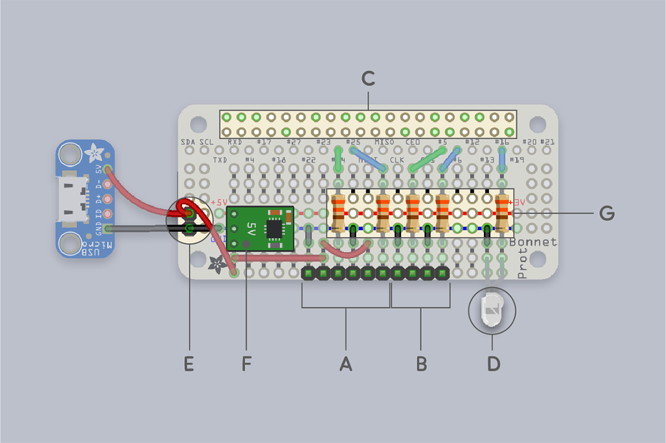
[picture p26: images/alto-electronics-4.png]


You can find the Fritzing file containing the wiring diagram you see above, [here](electronics/alto-proto-bonnet-unannotated.png). Make sure to follow the diagram carefully, paying particular attention to the orientation of the USB (labelled E) and power regulation (labelled F) PCBs. 

The power regulation PCB has three connections - Vout, Ground and Vin. The pin labelled VOUT should be connected facedown, to the red +5v rail of the protoboard. The middle ground pin on the power regulator should be connected to the GND rail of the protoboard. Leaving the Vin pin of the power regulator to be connected to the USB breakout on the protoboard as in the image below.

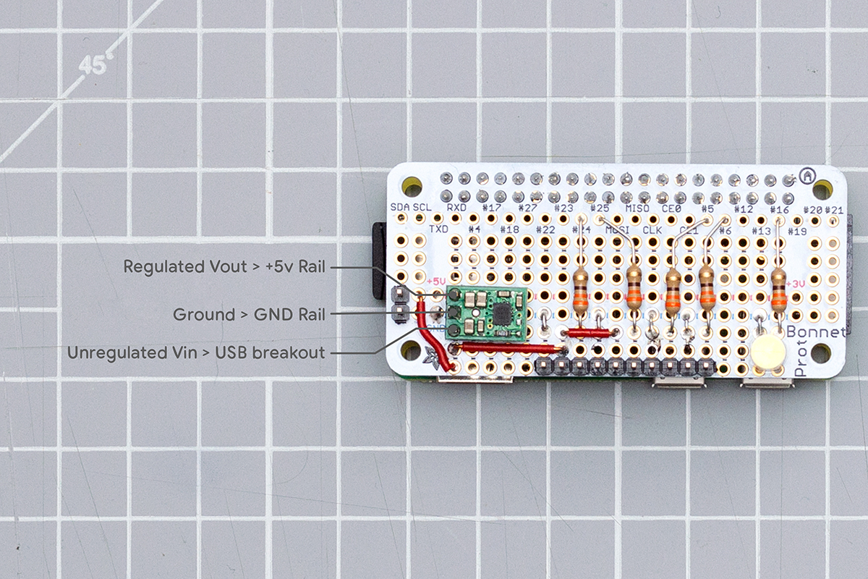
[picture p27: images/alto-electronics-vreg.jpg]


We have also provided a circuit diagram of the protoboard [here](electronics/kicad/alto.svg).<br>
<br>

### Option 2: PCB construction

If you want to assemble more than a couple of Alto units, you might want to consider having some PCBs fabricated. In this directory, you can find [kicad source files](electronics/kicad) and pre-exported [Gerber files](electronics/gerber). The assembly process for these boards is the same as the protoboard, and each connector is labelled in the PCB silkscreen.

As with the protoboard, you will need to solder on a 40 pin female header to connect the PCB to the Raspberry Pi Zero.

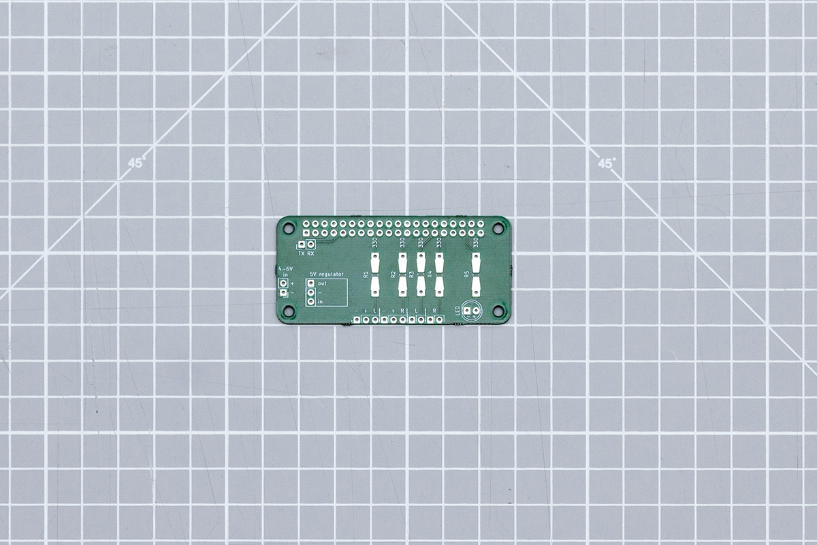
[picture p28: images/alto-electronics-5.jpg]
<br>
<br>

## Power options

The recommended way to power Alto is with the prefabricated USB power PCB circuitry specified in the BOM. This ensures smooth delivery of adequate power to Alto during normal operation.

The Raspberry Pi requires a tightly regulated 5V input. The current draw from the servos can mean the power supplied through a USB cable can fluctuate and isn’t appropriate to power the Raspberry Pi directly. Using the boost converter ensures a more stable delivery of power, and means we can accept a wider range of power sources - for example a 3.7V LiPO or 4x rechargeable AA batteries.

To use the suggested USB power circuitry, solder pin headers to the USB breakout board (if required) and then use two receptacle-receptacle jumper wires to connect the breakout to the protoboard or PCB. The first connection is between the ground pins, marked ‘GND’ on the breakout board and ‘-’ on the PCB. The second connection is between the positive pins, marked ‘5V’ on the breakout board and ‘+’ on the PCB.

Depending on your application, you can choose to power Alto by other means. Any alternative options should be carefully chosen to meet Alto’s power requirements. 

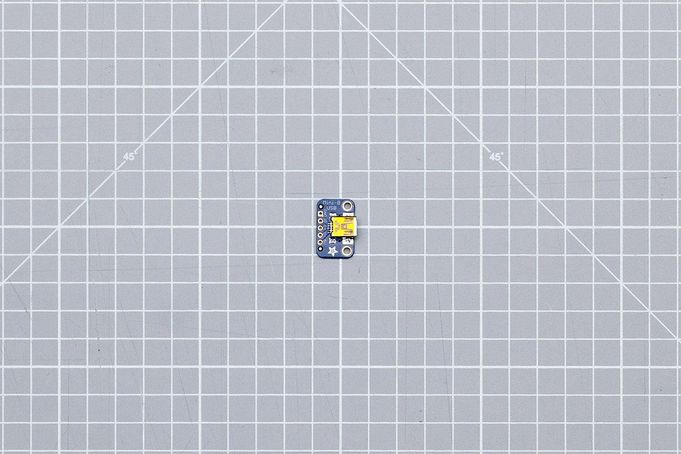
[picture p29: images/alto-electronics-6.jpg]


## Remote components

The buttons and servos used in alto are connected to the protoboard (or PCB) via leads as in the image below.

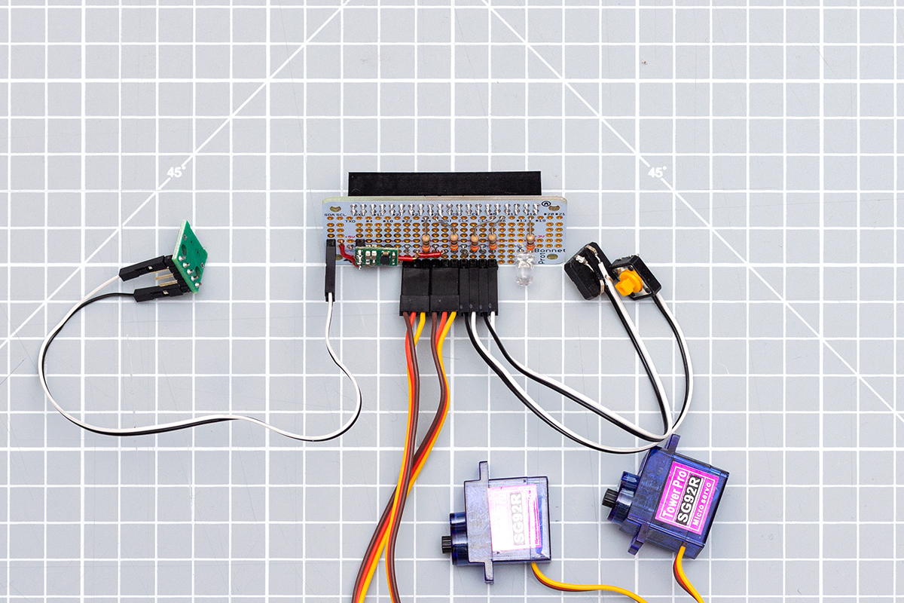
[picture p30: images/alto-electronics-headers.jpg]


 You should use roughly 10cm of cable for each of these. Regardless of the construction method you are using, you will need to attach your servos and buttons to the headers on your board. 

When you start to build the casing for your alto, you will find that the remote components are inserted into the housing before your Raspberry Pi, Coral and protoboard/PCB. We recommend preparing your ‘stack’ of electronics, before you begin to assemble the cardboard housing.

To test your electronics are working, connect them in this order:
1. Connect your Coral to the port labelled ‘USB’ on the Raspberry Pi
2. Attach the camera ribbon cable to the ribbon port on the Pi, making sure that the copper contacts are face down.
3. Gently press the port’s black clip in to secure the cable.
4. Using the soldered header pins, connect your protoboard/PCB to the Raspberry Pi as in the two images below.
5. Temporarily, connect your servos and buttons as shown in the illustrated PCB diagram shown previously.
6. Lastly, plug in your power source and turn it on.

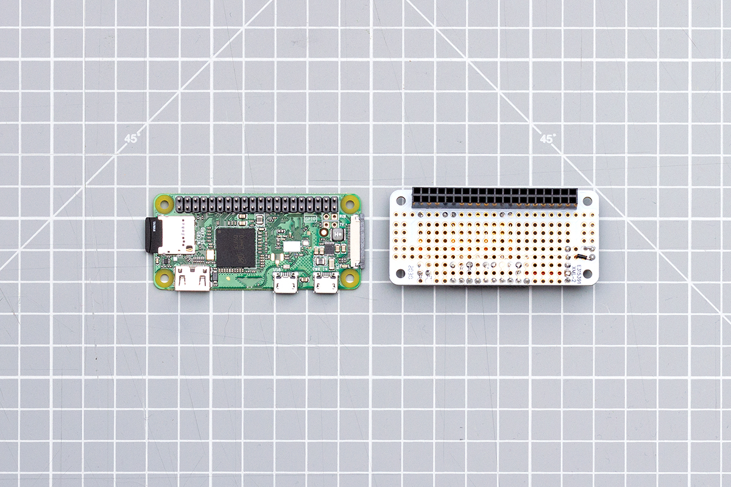
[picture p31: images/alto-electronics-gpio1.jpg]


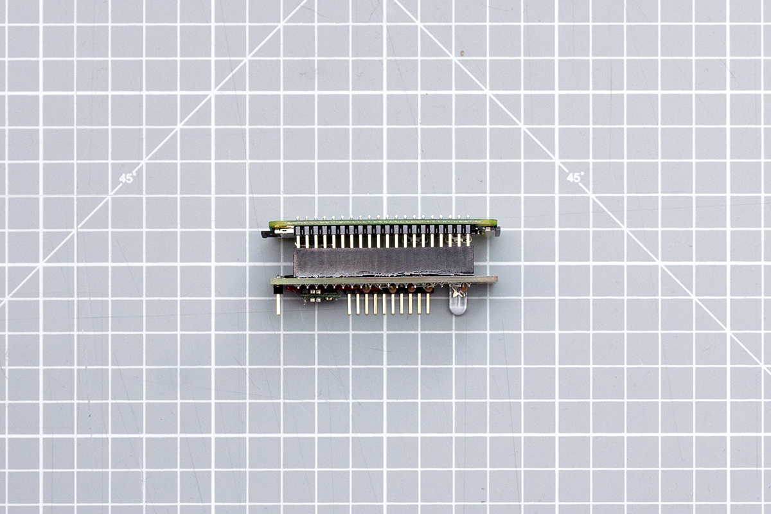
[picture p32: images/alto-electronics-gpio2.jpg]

<br>

After a few seconds, you should see the LED status light on your board turn on, and you can test the circuitry.

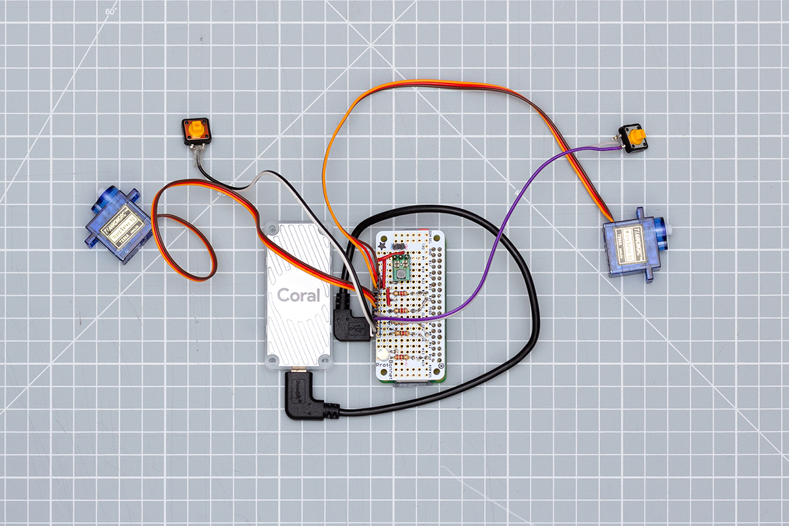
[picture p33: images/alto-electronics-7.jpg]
<br>
<br>

## LED status codes

On the Alto PCB there is a single LED which is used to communicate various status messages to help with debugging in case of error. These are as follows:

- Constantly on - no error, Alto is running as expected
- Two-flash blinks - the camera is connected incorrectly
- Three-flash blinks - the EdgeTPU is not detected

<br>
<br>

## :tada: Woohoo! You've finished this section :tada:

If you’ve completed all the steps above, you should now have a functional set of Alto electronics.

Before proceeding any further you might want to take a moment to make sure that everything is working as expected. Check that all connectors are connected as they should be (except the power connector) and that all solder joints look properly formed.

If everything looks good, plug in your appropriate power source. It will take between 15 and 30 seconds to boot Alto, depending on the speed of your SD card.

When Alto has finished booting, try teaching it something with one of the buttons. You want to make sure that all elements of Alto work properly before proceeding with assembly: learning on both sides; recognising on both sides; and forgetting.

If you have any errors, you can go back a step to check your software setup, or look back over the steps in this section to troubleshoot your electronics.<br>
<br>

## Next section &#8594; [3.1: Making the electronics casing](3.1-Making-the-electronics-casing.md)

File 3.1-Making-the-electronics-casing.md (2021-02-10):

# 3.1 Making the electronics casing<br>
<br>

This directory contains all of the source files you will need to construct the inner part of Alto’s casing. They’re provided as a starting point, but feel free to explore the designs and modify them for your own needs.

If you’re in the process of building Alto and have not yet set up your Raspberry Pi or built and prepared your electronics, we recommend you start with those first.

**Skills required**

- Accurate craft skills - cutting, sticking and folding

**Time to complete**
- 45min - 1hour

**What you’ll need**
- 2mm Cardboard (flute E)
- White card (300 gsm)
- Printer and paper
- Craft knife
- Stapler
- Metal rule
- Glue stick
- Bone folder (or a coin)
- Optional: Coloured card (blue, red, yellow)
<br>
<br>

## About the templates

- [alto-paper-templates.pdf](casing/alto-paper-templates.pdf)
- [alto-paper-templates.ai](casing/alto-paper-templates.ai)

Templates for the case design are provided above in both PDF and Adobe Illustrator format. Before you begin the step by step assembly, download the PDF and print it on white paper at 100% scale, making sure they aren’t scaled to fit the paper.

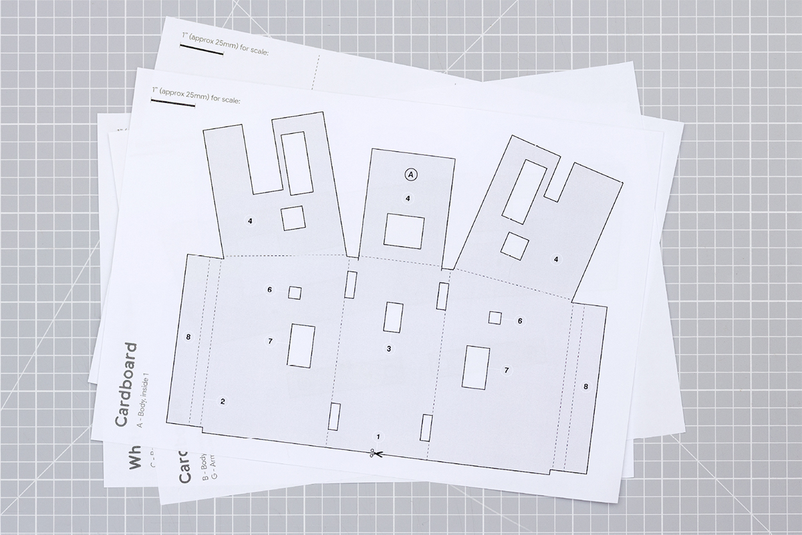
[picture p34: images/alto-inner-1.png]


:fire: Hot tip! You may use the Illustrator file if you wish to change the dimensions of Alto, or even prepare the document for laser cutting. The different cuts, folds, and texts have been separated into layers for easy conversion to DXF for laser cutting. Remember that you will have to calibrate your laser cutter to work with the materials you have chosen.

:warning: WARNING: this tutorial requires use of sharp tools such as craft knives. Please take care when using these tools, and supervise younger makers 
<br>
<br>

## Step by step assembly

1. Roughly cut out all your template pieces (A-G). Then:
- Glue (A), (B) and (G) onto 2mm cardboard
- Glue (C) onto thin white card
- Glue (D) onto thin blue card
- Glue (E) onto thin yellow card
- Glue (F) onto thin red card

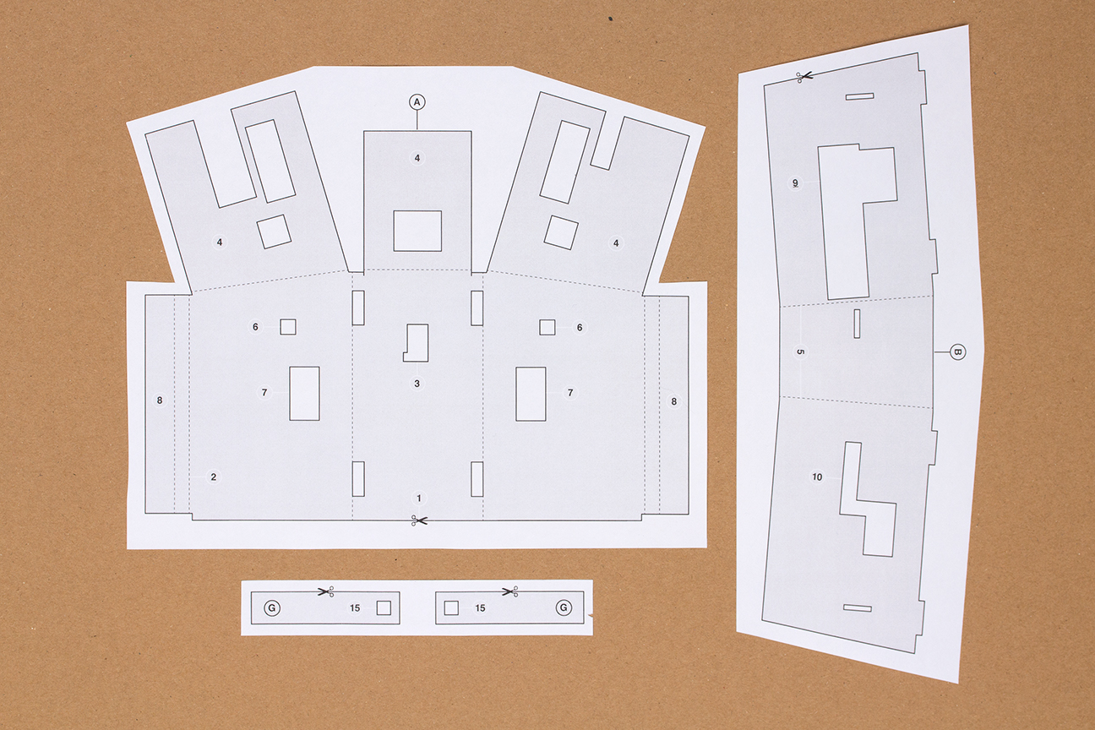
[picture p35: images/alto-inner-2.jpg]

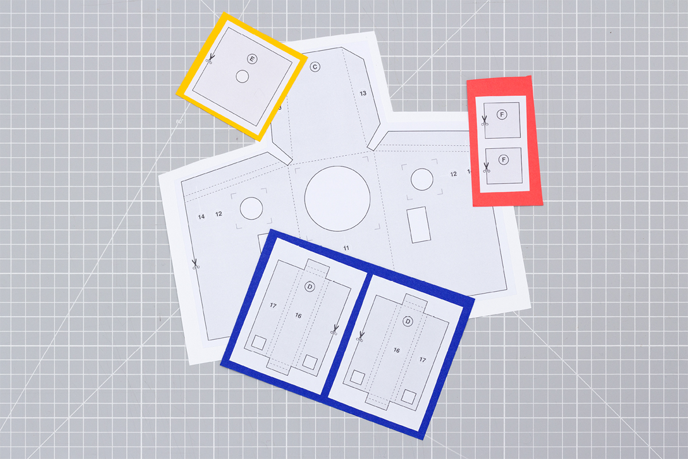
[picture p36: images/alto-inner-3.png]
<br>
<br>

2. Using the craft knife, cut out the pieces (A - G) along their thick black lines. We recommend starting with the cuts in the middle of the templates first, and doing the outside edges last.

:fire: Hot tip! With cardboard we recommend scoring lightly at first, and then doing a second cut to slice all the way through.

<br>
<br>

3. Press firmly along all the fold lines using a blunt object like a bone folder or the edge of a coin. Then prefold (inwards) along all those edges to make the assembly easier.

:fire: Hot tip! Score very lightly on the fold line to help you make the fold in exactly the right place.

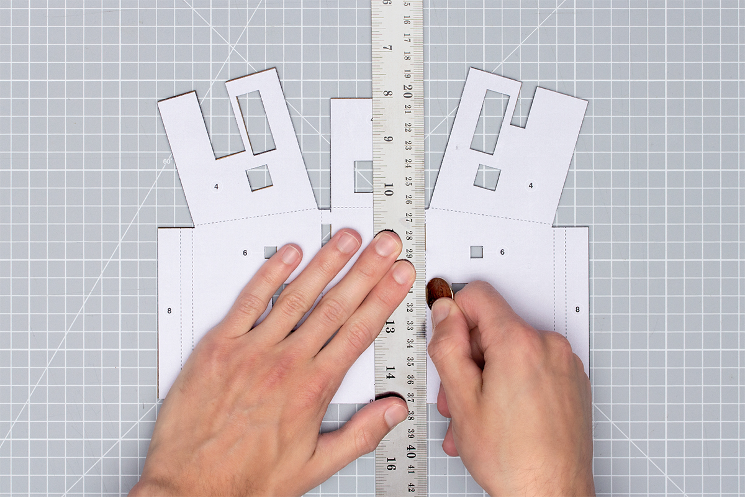
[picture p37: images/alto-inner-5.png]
<br>
<br>

4. Place the camera module carefully on (A) with the lens face down in the cavity labelled (3). Gently thread the ribbon cable through the hole above it as shown.

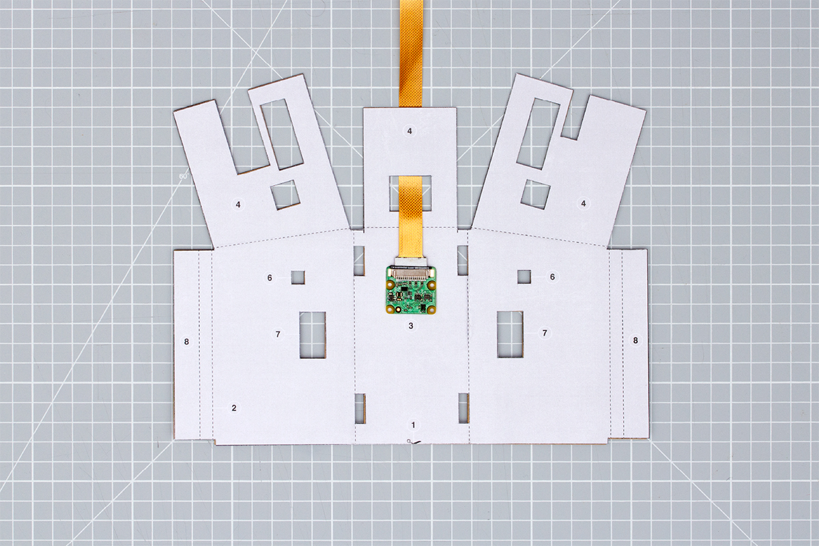
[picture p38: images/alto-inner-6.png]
<br>
<br>

5. Fold the tabs labelled (4) down and secure them in place by stapling the edges down.

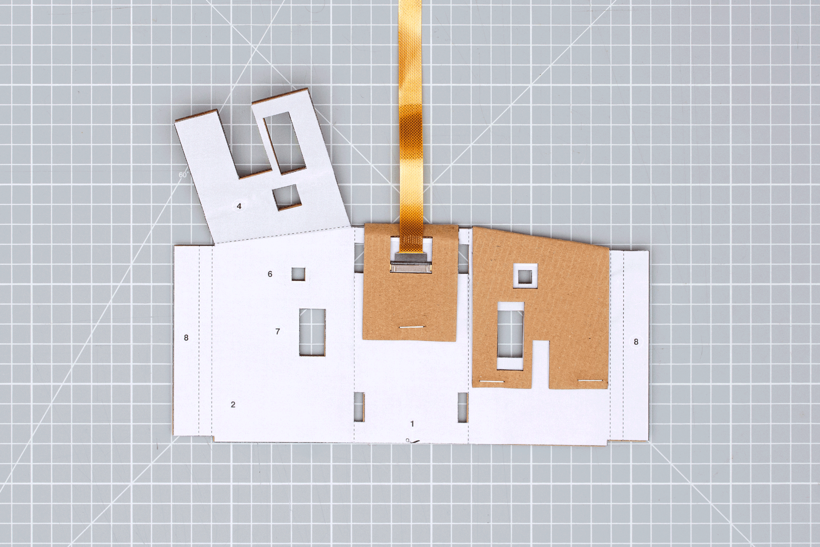
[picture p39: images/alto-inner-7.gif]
<br>
<br>

6. Take one of your buttons and snip off the unused legs. Press the button firmly into the cavity labelled (6), ensuring the cables are on the top side.

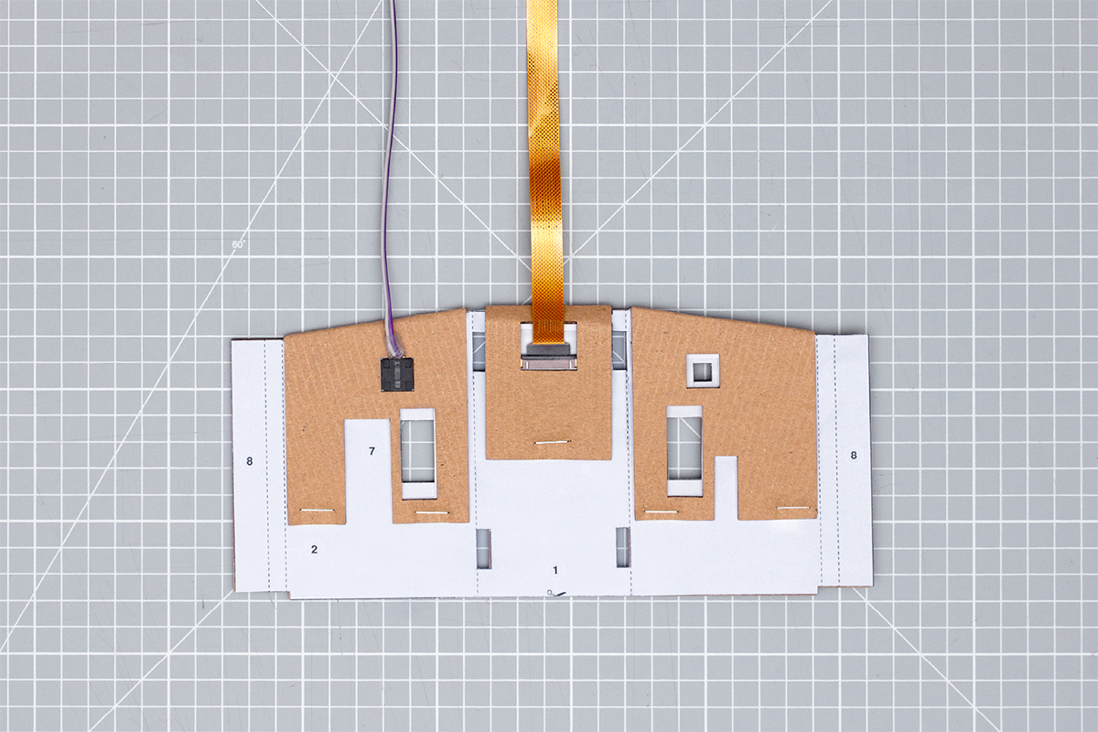
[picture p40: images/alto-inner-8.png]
<br>
<br>

7. Now do the same with your servo motor, into the cavities labelled (7).

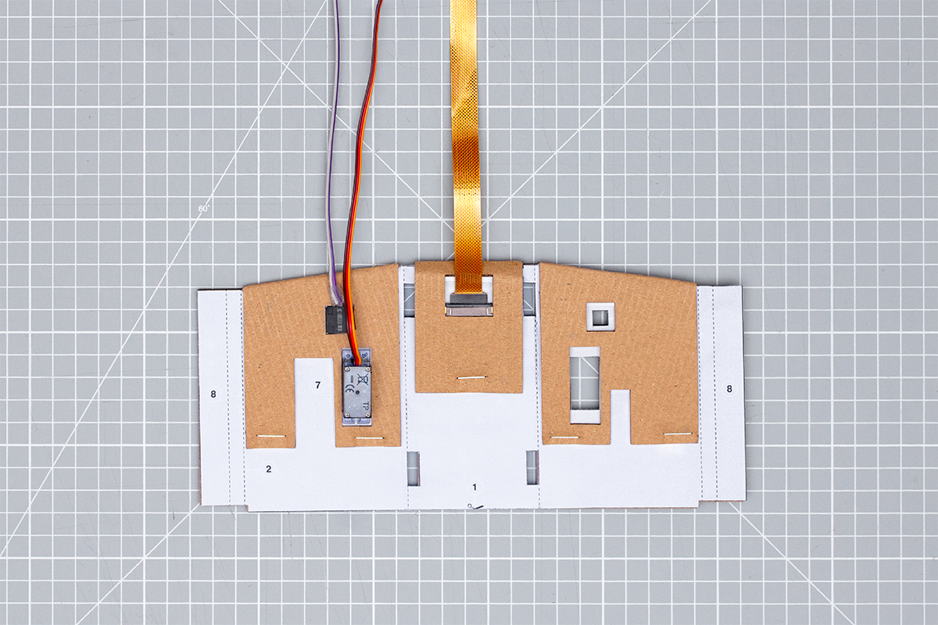
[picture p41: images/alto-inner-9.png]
<br>
<br>

8. Slot part (B) into (A) as shown, and thread the button and servo cables through their holes on (B). Then carefully fold up Alto’s side panel, ensuring the electronics are still in their place.

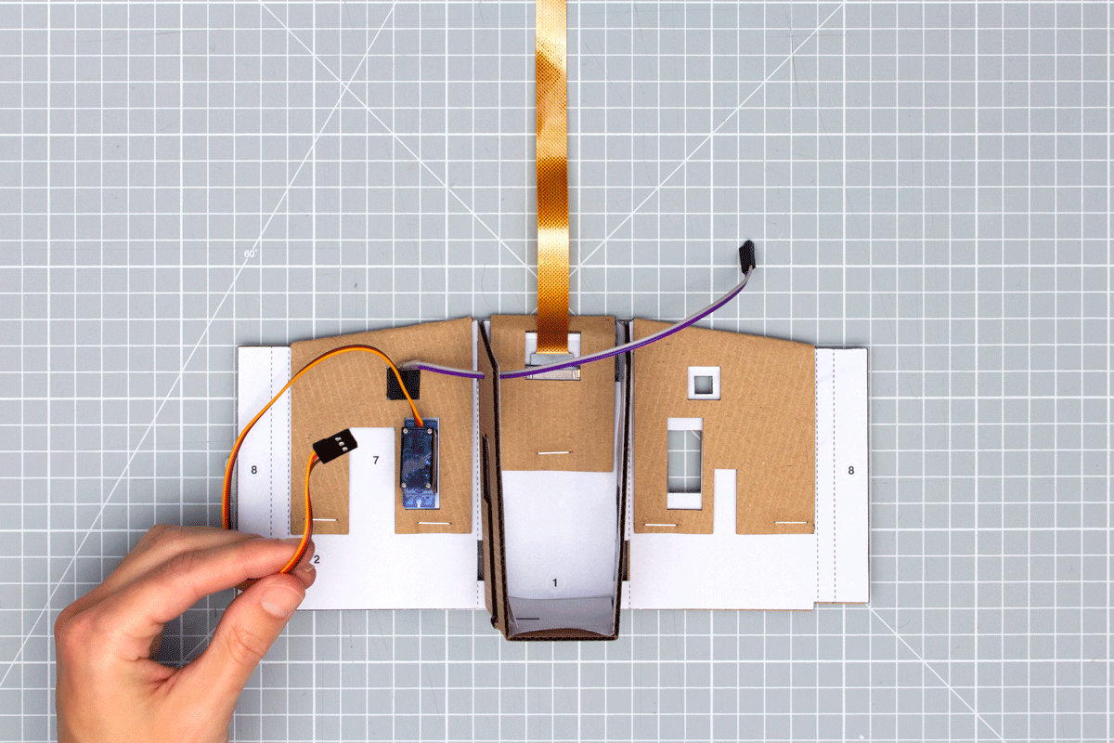
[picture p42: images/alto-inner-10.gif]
<br>
<br>

9. Holding everything tightly together, fold in the wing labelled (8) on part (B). Make sure it wraps around to the inside of Alto and use a stapler along the inside face to ensure it’s secure.

:fire: Hot tip! If your staples aren’t long enough, try stapling from the outside face in addition to the inside face.

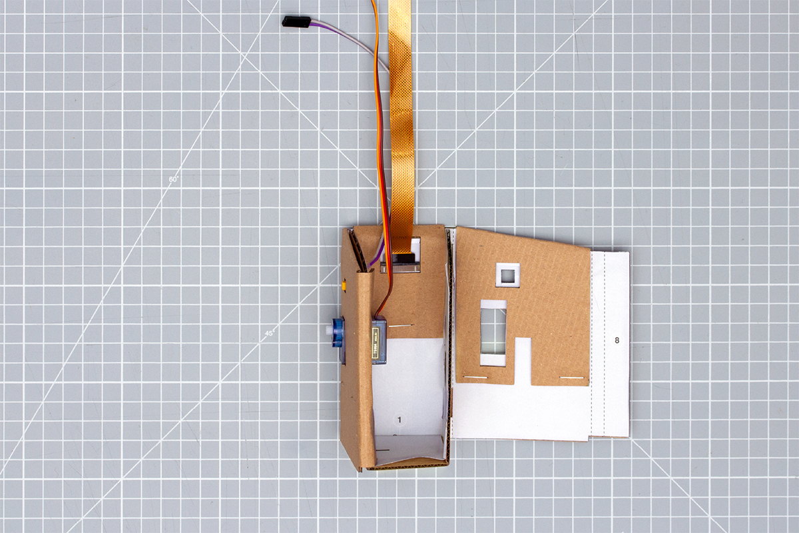
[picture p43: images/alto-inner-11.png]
<br>
<br>

10. Then repeat steps 6-9 on Alto’s other side.

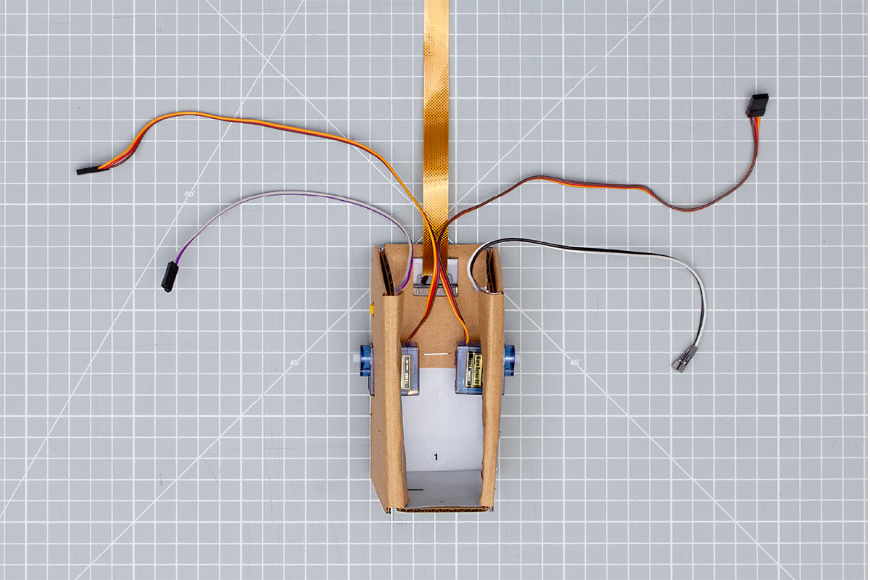
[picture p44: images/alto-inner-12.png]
<br>
<br>

11. With your cable on the right hand side, slip your stack into Alto from the top. The Pi and protoboard should fit snugly into the cavity labelled (9), allowing access to the SD card slot from underneath Alto. The right-angled cable should then fit into the cavity labelled (10).

<br>
<br>

12. Place your Coral USB Accelerator down behind your servos so that you still have access to your headers.

<br>
<br>

13. Using the diagram below, connect your cables up to your protoboard headers, making sure you haven’t mixed up the left and right side buttons and servos. Attach the Pi camera ribbon cable to the Raspberry Pi connector, with the copper pins facing the PCB. 

:warning: Careful: the ribbon cable is very delicate, so try to avoid folding, twisting or creasing it as much as possible.

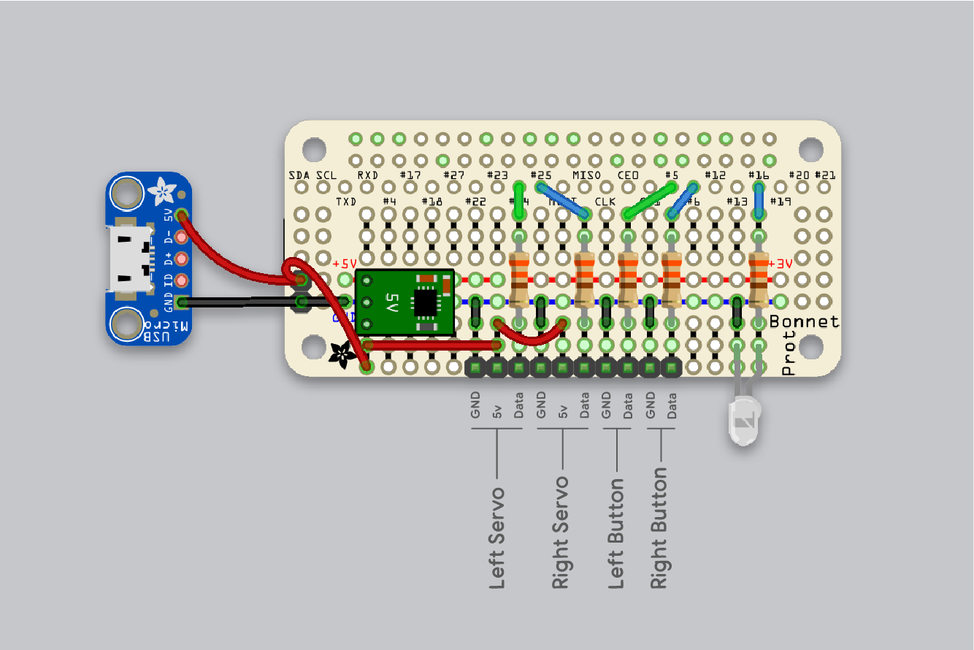
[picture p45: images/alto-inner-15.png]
<br>
<br>

14. Once you've connected all your cables, you should have something that looks like the image below. Try and tuck the cables in around the electronics, but be careful not to disconnect anything. Don't worry too much if you still have some stray cables, as these will be held in place once you put on Alto's outer case.

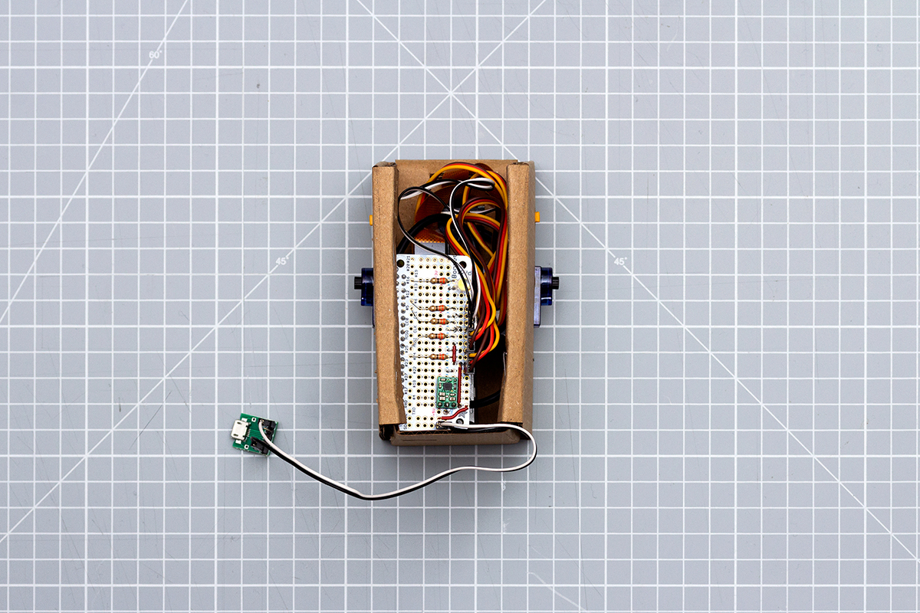
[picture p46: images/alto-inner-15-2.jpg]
<br>
<br>

## :tada: Woohoo! You've finished this section :tada:

If you’ve completed all the steps above, Alto should be starting to take shape. All the electronics should now be safely housed in the brown cardboard casing, and waiting for the final exterior card case and arms.

Before going further you might want to take a moment to make sure that everything is still working as it should. It's common for jumper wires to come loose, or poor solder joints to be exposed during the process of housing the electronics. Remember, the camera cable is particularly delicate.

If things aren’t working, start by checking all your connections. If they all look good, go back to the software or electronics sections to double check you completed them before going further.<br>
<br>

## Next section &#8594; [3.2: Making Alto's outer case](3.2-Making-altos-outer-shell.md)

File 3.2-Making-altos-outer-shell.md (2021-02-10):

# 3.2 Making Alto's outer casing<br>
<br>

In this section, we’ll be adding some character to Alto by creating the outer shell. In addition to giving Alto some personality, this outer layer helps contain the electronics, and keep the inner card structure more secure.

By the end of this section, you’ll have finished your build, and have a fully functional Alto!

**Skills required**
- Accurate craft skills: cutting, sticking and folding

**Time to complete**
- 45min - 1hour

**What you’ll need**
- 2mm Cardboard (flute E)
- White card (300 gsm)
- Printer and paper
- Craft knife
- Stapler
- Metal rule
- Glue stick
- Bone folder (or a coin)
- Optional: Coloured card (blue, red, yellow)
<br>
<br>

## Assembling your outer case

15. Next we are creating Alto’s outer shell, starting by taking the coloured elements we made in Section 3.1 and glue them to the main body (labeled part C on your print out).
- Glue Alto’s yellow eye (E) onto the part labelled (11)
- Glue its red ears (F) onto the part, labelled (12)

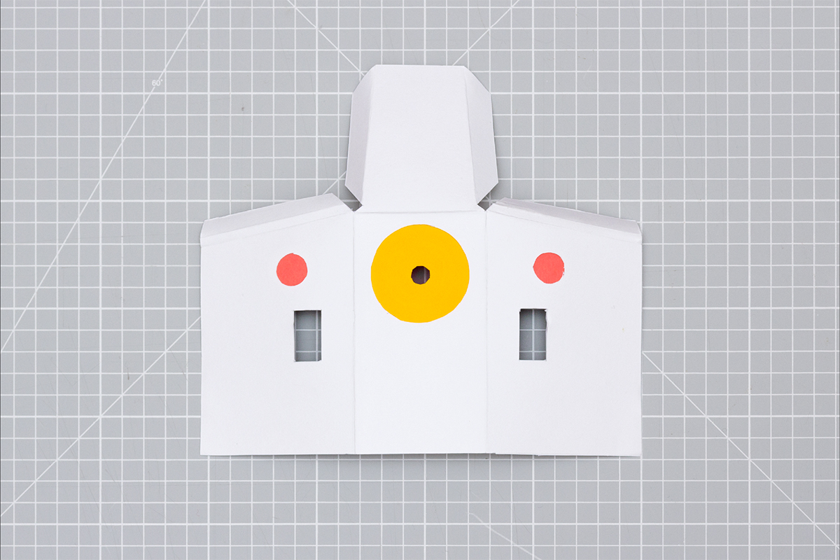
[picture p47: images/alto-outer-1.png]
<br>
<br>

16. Place cardboard Alto face down, in the middle of part (C).
- Fold the top part of (C) downwards, slipping the tabs labelled (13) between the layers of cardboard
- Then fold in the sides of (C), doing the same as before with the tabs labelled (14).

:fire: Hot tip: make sure the white card folds are as tightly creased as possible so that Alto’s edges are crisp - this will also help hold all the faces together.

<br>
<br>

17. To make Alto’s arms, start by taking the white plastic arm from your Servo motor kit, and inserting it into the cavity (15) on part (G). Then carefully staple through the arm and the cardboard to secure them together.

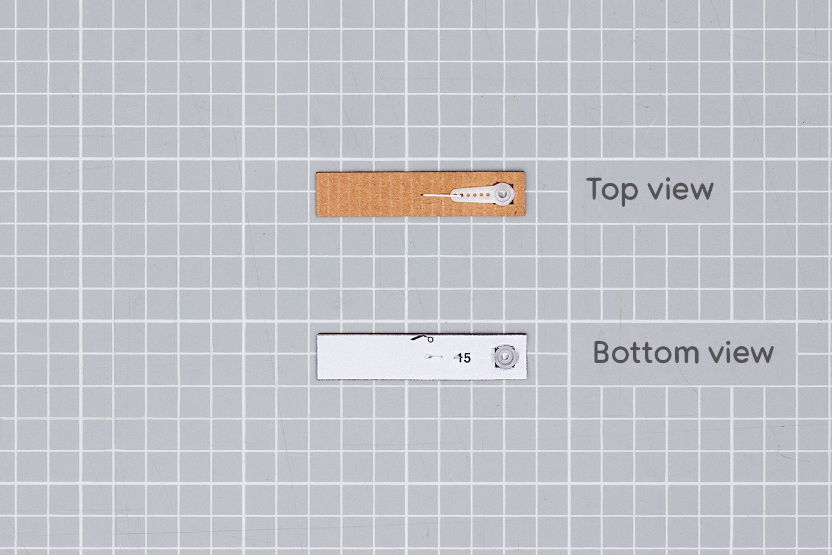
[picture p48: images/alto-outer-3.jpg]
<br>
<br>

18. Place the cardboard arm onto the face labelled (16) on (D), with the stapled white servo arm face down. Then fold in all the tabs, with the face labelled (17) last, and staple the two ends to secure the card around the cardboard.

<br>
<br>

19. Now do the same with the second arm. When ready, press Alto’s arms onto the servo shafts. This should be a push fit, however you can use the screws that came with the Servo motor if you would like to make them more secure.

:fire: Hot tip: when you first power Alto on, the servo motors naturally return to their zero position (arms down). If Alto’s arms are out of position, pop them off and put them back on so that they are down by its side.

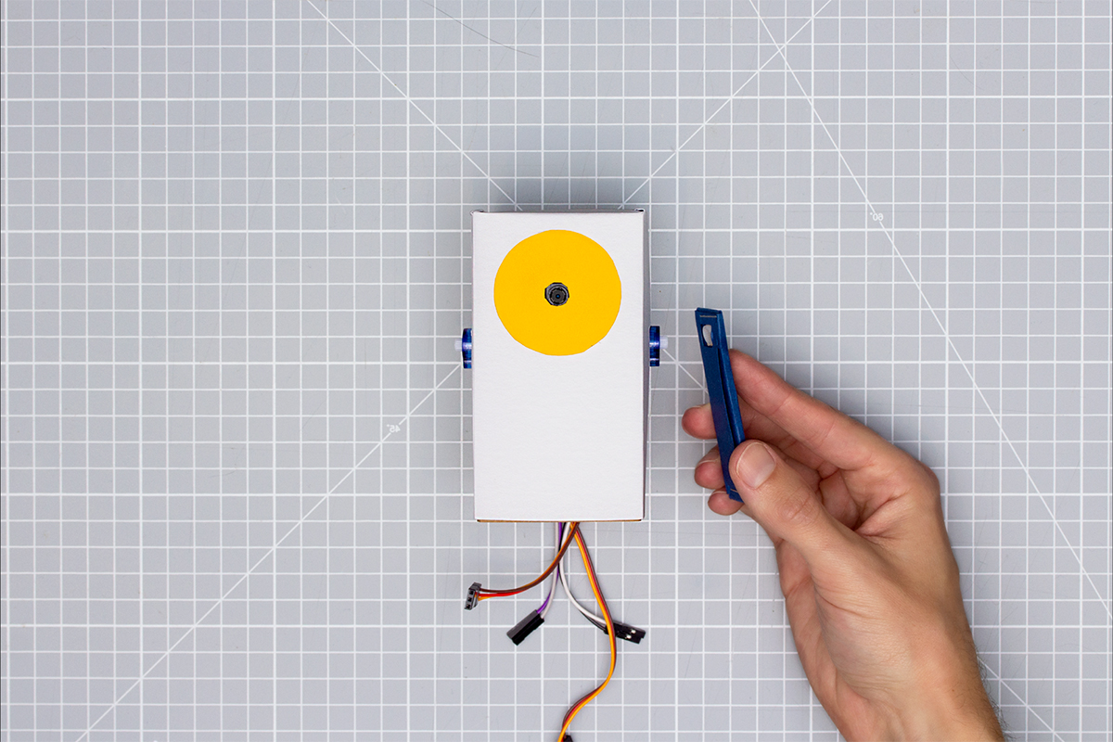
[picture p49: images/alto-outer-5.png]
<br>
<br>

20. Connect the servo and button cables as in [Section 2: Build the electronics](2.0-Build-the-electronics.md), then plug Alto into your power source, and you’re done!

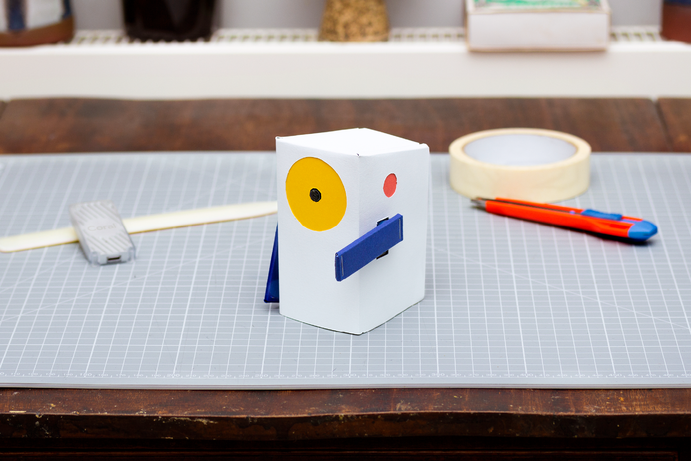
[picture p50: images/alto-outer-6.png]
<br>
<br>

## :tada: Woohoo! You've finished this section :tada:

If you’ve completed all the steps above, you should now have a fully functional Alto, complete with housing. Congratulations!

Start playing with Alto to test your build and better understand how the system works. If things don’t behave as expected, go back through the build steps to see where things went wrong. If you want a more structured guide for using Alto, take a look at the [‘Experiment with Alto’](4.0-experiments-with-alto.md) section of this repo.

If you’re feeling adventurous, why not try hacking Alto to do different things, or simply experiment with the casing design. You can see some examples of how we have remixed Alto [here](5.0-remixing-alto.md). If you come up with any cool edits, share them online to inspire others. Or submit a project to the [Experiments with Google site](https://experiments.withgoogle.com/) if you find a completely new way of using the Coral USB Accelerator.<br>
<br>

## :star: Bonus section &#8594; [Remixing Alto](5.0-remixing-alto.md) :star:

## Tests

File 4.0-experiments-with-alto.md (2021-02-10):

# Experiment with Alto <br>
<br>

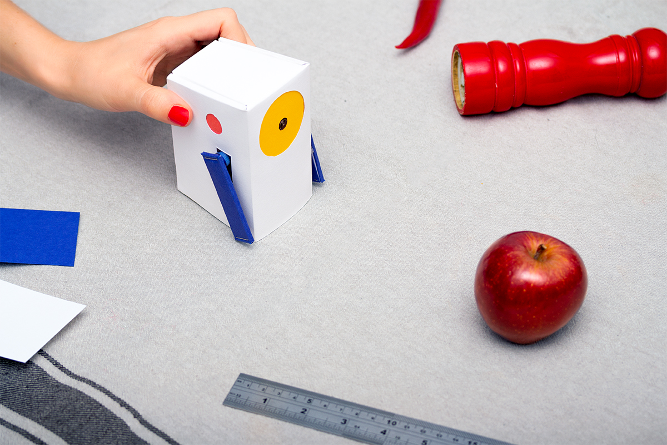
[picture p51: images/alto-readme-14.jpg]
<br>
<br>

## Understanding Alto

This document contains a number of experiments to help understand how Alto works, and how you can use Alto to introduce some of the basic concepts of machine learning to others. 

Alto is a simple (and fun!) way to understand these concepts. The more you use Alto, the better you will understand the capabilities—and limitations—of machine learning. If you’ve already built your Alto, you can use it directly with the activities in this document. If you haven’t built your Alto yet, you should [go back](1.0-Set-up-the-software.md) and do that first. 

This document is split into two sections:
1. [Learning by doing](#learning-by-doing) - a range of simple, hands-on experiments that show you how to operate Alto, and illustrate some of the basic concepts of machine learning.

2. [Under the hood](#under-the-hood-how-alto-works) - a more indepth look at some of the more technical details of Alto, and an illustration of what's happening under the hood.
<br>

## Learning by doing

### Operating Alto

In this section, we recap Alto’s controls, by completing the simple process of teaching Alto to recognise an object, testing that Alto can recognise what you’ve taught it, and erasing Alto’s memory to start again afresh.

There are three basic things that you can do with Alto:

- [Teaching](#teaching)
- [Recognising](#recognising)
- [Forgetting](#forgetting)
<br>
<br>

### Teaching

Teaching Alto is very easy: 

1. Choose your object and place it in front of Alto, facing the camera. 
2. Press one of the buttons on the side of Alto to start the teaching process. While it’s learning, Alto will slowly raise the arm on the same side of the button that you pushed. Alto uses the camera to take 40 sample pictures of the object to learn about it. 
3. When Alto’s arm has reached roughly 90º, the teaching process has finished, and Alto is ready to recognise what it’s learned.

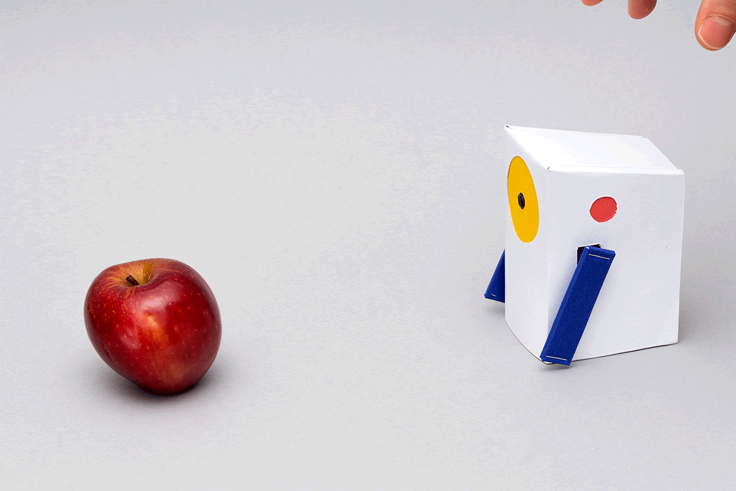
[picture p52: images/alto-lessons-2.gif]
<br>
<br>

### Recognising

As soon as the teaching process has finished, Alto automatically enters recognition mode. There’s no user input needed for Alto to begin evaluating the things it sees: if something is recognised by Alto, it will point with the corresponding arm. For example if you placed a red apple in front of Alto during teaching, it will raise the corresponding arm when the red apple is placed in front of it again in recognition mode. 

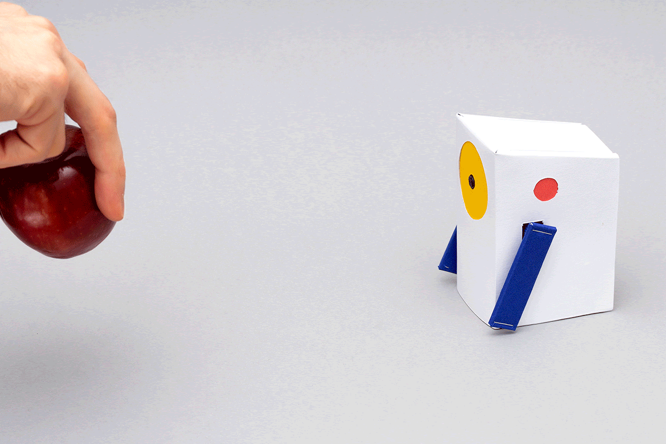
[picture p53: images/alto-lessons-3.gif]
<br>
<br>

### Forgetting

If you want to teach Alto something new, you can clear everything it's been taught by holding down both buttons simultaneously for 3 seconds. This will clear the memory of everything you have taught Alto on both sides.

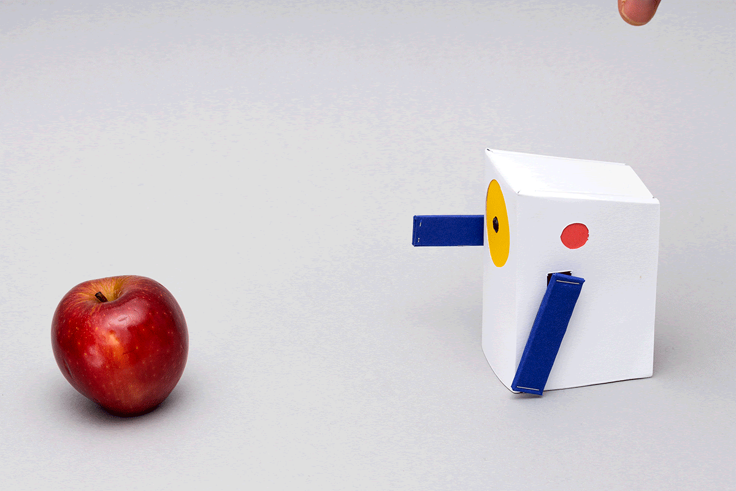
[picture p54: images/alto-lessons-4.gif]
<br>
<br>

## Experiment One: simple object recognition

The first experiment covers the basics of how you can use Alto to recognise an object, and how to set up your teaching environment to get the best results.

<br>
<br>

### Teaching Alto to recognise an object

As we’ve already seen in the [operating Alto](#Operating-Alto) section, you can teach Alto to recognise what it sees using the buttons on either side.

Alto will work best in a location with good lighting and a plain background. This can help ensure its camera can capture the object you want it to recognise clearly. When you’ve found your spot, place Alto down and power it on.

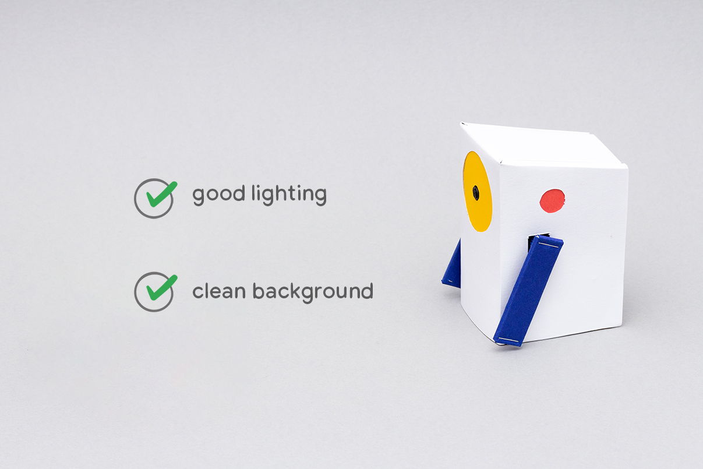
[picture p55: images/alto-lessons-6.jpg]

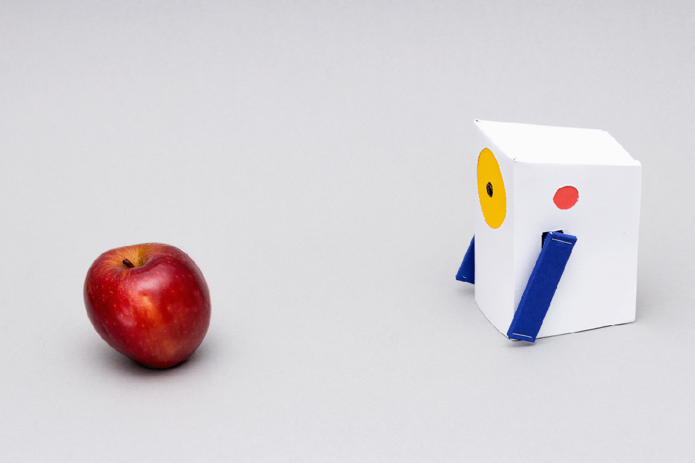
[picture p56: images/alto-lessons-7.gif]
<br>
<br>

Next, choose an object and place it in front of Alto. We’ve chosen this shiny red apple. 

To start teaching Alto, press one of the side buttons; Alto will learn about the object it sees by taking pictures of it.

As we’ve seen before, when Alto has finished learning (when it has fully lifted its arm to 90°) , it automatically switches to recognition mode. Now, everytime Alto sees the red apple, it will point at it.

Well done, you’ve just completed your first machine teaching experiment! Easy!<br>
<br>

### Other things to try

You can wipe Alto’s memory to start again and teach it about a new object. Try exploring different objects to teach to Alto. Do they all work equally well? 

Try experimenting with different setups to teach Alto - change how close or how far the object is from Alto when you teach, and when Alto is recognising. Try teaching Alto in different environments, with different lighting and backgrounds. What does Alto’s behaviour tell you about the teaching and recognising process?<br>
<br>

### Bonus: Pattern recognition

By now, you should have been able to get Alto to recognise a variety of different objects. This is great, but you might be wondering what Alto can do beyond recognising apples and bananas. 

In addition to objects (that humans find easy to recognise), Alto can also remember quite complex things that might be much harder for us to see.

Look at the two patterns below. At first glance, they look the same, but looking closer, you might be able to tell that they are both in fact slightly different. 

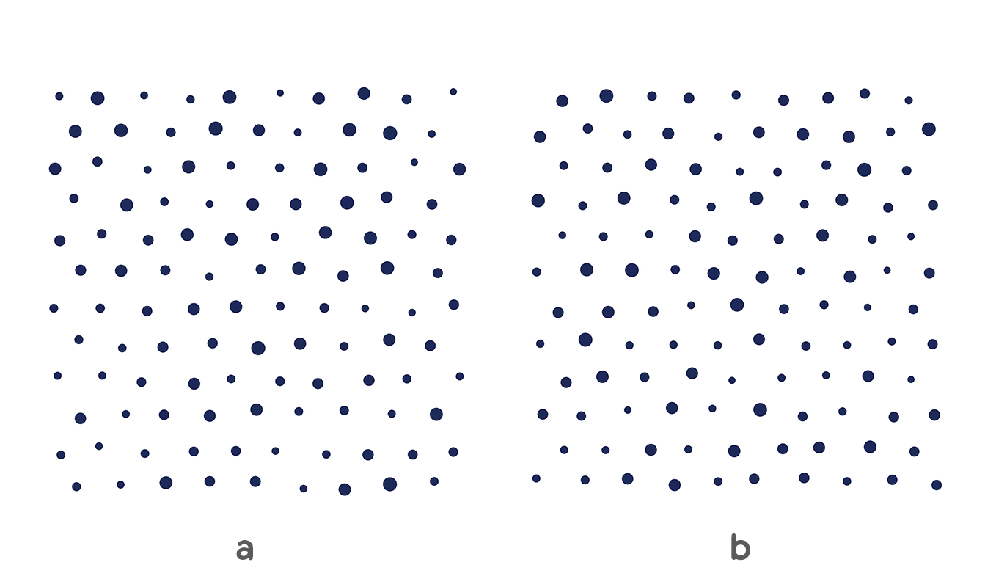
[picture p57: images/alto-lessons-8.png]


In this experiment, we’ll test Alto’s memory against a real person, to see who’s better at accurately remembering a chosen pattern. Who do you think will be able to remember the correct pattern more easily and why? 

First, find a partner to help with this experiment. Next, print out the [patterns](extras/alto-lessons-test.pdf), and teach both of them to Alto three or four times - one side for each pattern. Then show the patterns to your partner, making sure to cover the labels. To make it fair, show them to your partner for the same amount of time you showed it to Alto. And be sure you always show it to Alto (and your partner) in the same orientation that you used to teach it.

Shuffle the patterns and then time how long it takes both Alto and your partner to identify the right pattern.

So, who did better? Is this what you predicted? Why do you think this might have been the case?

After completing these experiments, you’ve started your journey into machine learning! Although the process is simple, the things you’ve learnt form the basis of how Alto works in any situation - teach, recognise, forget. 

We’ve seen that Alto can recognise different objects and even quite complex patterns, but can also get things wrong that seem obvious to us. Why might this be?<br>
<br>

## Experiment Two: recognising two things

In the previous experiment, we learnt how to teach Alto to recognise and then recall one object. In this experiment, we’ll go a step further to show how Alto can be taught to remember two different objects simultaneously.

<br>
<br>

### Teaching Alto about two things

For this experiment, you’ll need two objects that are visually different. We’re using a red apple and a banana.

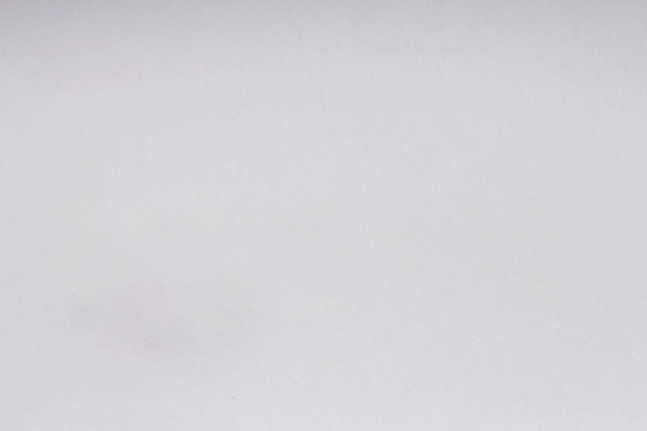
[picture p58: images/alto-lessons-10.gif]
<br>
<br>

Start by clearing Alto’s memory to erase anything that might be there already. 

Once that’s done, teach Alto about one of your objects. As before, once completed, Alto should now recognise that item. Check that it can recognise the object as you’d expect before moving on.

Now it’s time to teach Alto about a second object. Keeping Alto in the same place, replace the first object with the second one. Then use the button on the other side of Alto to teach it about this new object. This time, Alto will point with its other arm.

You should now be able to alternate between the two objects, and Alto should be able to recognise each one. In our case, Alto can now tell the difference between red apples and bananas!<br>
<br>

### Other things to try

This is a simple experiment, but the ability to distinguish between objects can be used in many applications. In industry, you might need a similar system to separate different types of products in a factory, or you might just want to sort out the [marshmallows from your cereal](https://coral.ai/projects/teachable-sorter/).

Try exploring different objects for Alto to distinguish between. What sort of things can Alto easily distinguish, and what objects does it mix up? Why might this be, and how could you adjust your teaching process to get better results?<br>
<br>

## Experiment Three: adding more data

So far, you’ve seen how Alto can very simply, and quickly be taught to recognise objects on each side. In this experiment, you’ll explore how to teach Alto about these objects multiple times, to improve Alto’s ability to recognise them. 

This practice of multiple teaching cycles will also introduce us to the ideas of ‘bias’ and ‘confidence’ within machine learning.

<br>
<br>

### Adding more data

As you might have seen in the previous experiments, it can be hard to remember something clearly if you haven’t seen it for very long, or from only one perspective. Like all of us, Alto can remember something better the more you teach it about it.

To teach Alto about something multiple times, you simply follow the same teaching process already covered, but don't wipe Alto’s memory in between times. 

With each new teaching process, you’re adding data to Alto to help it recognise what it captures with its camera. It's important to remember which side you’re teaching Alto on, so that you don't mix up the data. 

So why might you want to do this? 

In some of the previous examples, you might have seen times where Alto doesn’t immediately recognise something you’ve already taught it. There are lots of reasons why this might happen, but one common one might be because the object is in a different position to when you first taught Alto. 

Alto can only remember what it's been shown. This is an important point to remember. If we shift our example object from apples to mugs, we can test this idea out. 

We know we can easily teach Alto to recognise a mug by following the same process we did previously.

<br>
<br>

But if we turn this mug on its side, Alto doesn’t recognise it anymore. Even though it's the same object, Alto has never seen it from this angle, and has never been taught it's the same mug. This is something that we can do very easily, but learning machines like Alto can struggle with without more training.

For Alto to recognise this as the same mug, it needs to be taught with more images of the mug at these different angles to give it more information. 

If we teach Alto again on the same side, with the mug in this position, Alto should now recognise the mug when it's standing upright or on its side.

You can repeat this process as many times as you like, from different angles or distances. The more you teach, the better Alto should be at recognising the mug in lots of different positions. This can also be a useful feature to help Alto distinguish between two similar objects.

### Other things to try

In experiment two, we saw how you can teach Alto about two different objects. You might have found that Alto sometimes struggled to tell similar objects apart. Try picking two objects that look similar, and teach Alto about them both - one on each side. Next, try adding more data to each side, by teaching Alto about the objects multiple times. 

Does Alto get more reliable at telling them apart as you add more data?<br>
<br>

### Bias in machine learning

We’ve seen that adding more data by teaching multiple times can help Alto recognise objects more successfully. This can be a very useful feature, but it can also lead to a potential problem: bias.

Put simply, it's important to try and balance the amount of learning Alto does on each side. For example, If you teach Alto to recognise red apples 10 times, but only teach Alto to recognise green apples once, it will likely be much better at recognising red apples than green ones. Here we would say Alto was biased towards red apples. You can try this out yourself.<br>
<br>

## Experiment Four: teaching Alto about classes

So far, you’ve seen how Alto can be taught to recognise specific objects. But Alto can also be taught to recognise types of objects, called classes.



Thinking again about our red apples and bananas example, we’ve already seen that it's easy to teach Alto to recognise one specific red apple and yellow banana. We’ve even shown how we can teach Alto about these fruit multiple times, so it can recognise them from any angle.

But imagine we were trying to build a machine to sort between red and yellow objects in general. In this case, it's not much good if Alto can only recognise these two specific fruit. We need a system that lets Alto distinguish between other types of objects that are these colors.

One way to do this is to use Alto’s two buttons to teach it two different classes of objects - red ones and yellow ones. This uses the same process we’ve covered when teaching Alto multiple times on each side.

To try this out, 
1. Gather as many red and yellow objects as you can find. 
2. Set Alto up for teaching as normal.
3. Pick one side to be your red class, and the other to be your yellow class (you might want to make a note of which is which)
4. Go through the teaching process as normal for each object, remembering to teach Alto on all the red objects on one side, and all the yellow ones on the other.

You’ve now created two classes for Alto to recognise! See if it’s worked by putting the various objects in front of Alto and checking which arm is pointing.<br>
<br>

### Generalising

Creating classes with Alto lets you use many more objects at once, but so far we’ve still been limited to the objects we have at hand to teach Alto with. The red/yellow sorter we just made is great, but what if you wanted Alto to be able to distinguish between any red or yellow object? 

We can’t teach Alto about every possible red or yellow object, so we need to teach it about lots of different red and yellow objects—so many that when it sees a red or yellow object it hasn’t seen before, it can recognise that too. 

To try this out, find a new red or yellow object that hasn’t been used to teach Alto. Depending on the amount of data you’ve used to make your classes, Alto might be able to correctly classify this object already.

If not, try teaching Alto more about the objects you have, or find other red/yellow objects to add to the class. Can you give Alto enough data to get a successful classification for an object it hasn’t seen before?<br>
<br>

## Under the hood: How Alto works

In this section we’ll take a look under the hood of Alto, to understand a bit more about how it works. The world of machine learning and image understanding is vast! This isn’t a comprehensive guide to either of these topics, but rather a more detailed look at Alto in particular.

If it peaks your curiosity about machine learning more broadly, there are many wonderful introductory guides online, including a [crash course from Google](https://developers.google.com/machine-learning/crash-course/ml-intro).<br>
<br>

### What Alto 'sees'

Alto uses the Raspberry Pi camera to take images of the world, which it uses to classify the objects that it can see. Although we use terms like ‘seeing’ and ‘remembering’ it's important to understand that Alto interprets the world very differently to us.

Alto sees things as a grid of pixels. Except, to Alto, a pixel is just an array of numbers representing red, green, and blue color values. When you teach Alto about an object, it uses its camera to take lots of photographs, looking for patterns in those pixels. But it doesn’t have any understanding of what that object actually is, it just runs the color values through a lot of math equations, making its decision based on a long sequence of mathematic results. That’s why we can sometimes get unexpected outcomes, with Alto struggling to distinguish between things that seem obvious to us.<br>
<br>

### How Alto recognises images (advanced)

When you press one of Alto’s buttons, you’re teaching it an example of what to classify as either left or right. Each example image is processed through a neural network on the Coral Edge TPU, to create a numerical representation (a vector), which is then added to the corresponding set.

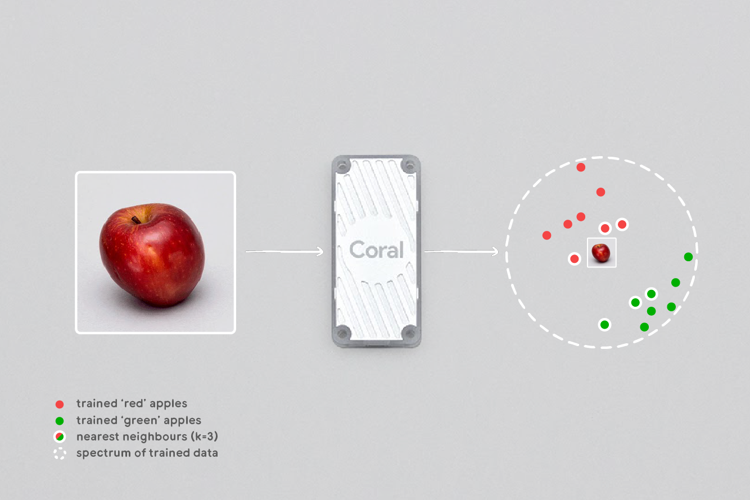
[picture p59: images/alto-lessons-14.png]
<br>
<br>

After the teaching process has finished, Alto starts streaming images from the camera, trying to classify them into either the left or right set. Each image is processed through the same neural network to create its vector. This is then compared to every stored vector in the left set to determine how closely it matches anything it was trained on. Alto uses a [k-NN (k-nearest neighbours)](https://coral.ai/projects/teachable-machine/#k-nearest-neighbors) algorithm to give a match confidence based on the top closest results on that side. 

This process is then repeated for the right side. If confidence is high enough on either side then Alto will point using the side with the highest confidence.

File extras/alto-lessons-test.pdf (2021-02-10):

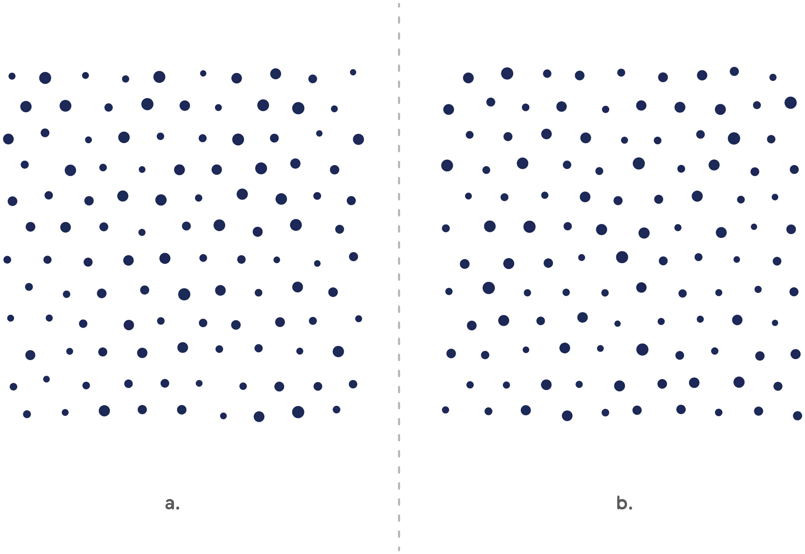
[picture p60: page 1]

a. b.

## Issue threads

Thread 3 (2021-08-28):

Alto does nothing but blink 10 times every 25s

hierophect, 2021-08-28:
Hello, we're putting together Alto for a machine learning video and are encountering some difficulty. We're using the provided image, flashed with Balena, and Alto appears to set up fine when used with a monitor and keyboard. But when run independently with the electronics, mostly all it does is sit with the LED off, and blink 10x at about 0.5s spacing every 25s. It does not respond to any input when in this state.

I say mostly because it seems to have entered proper operation a couple times, sporadically - the light will suddenly hold steady green, and you can train it on one object as expected with one of the servos gradually increasing, etc. However, it will then turn back off, and won't be responsive to any form of input after that.

I'm not sure what could be causing this looking at the main alto code - I see it does have a 10x repeat error blink condition, but it should be blinking multiple times to indicate a specific error, not just once. The whole thing seems a bit fishy so any help would be appreciated.

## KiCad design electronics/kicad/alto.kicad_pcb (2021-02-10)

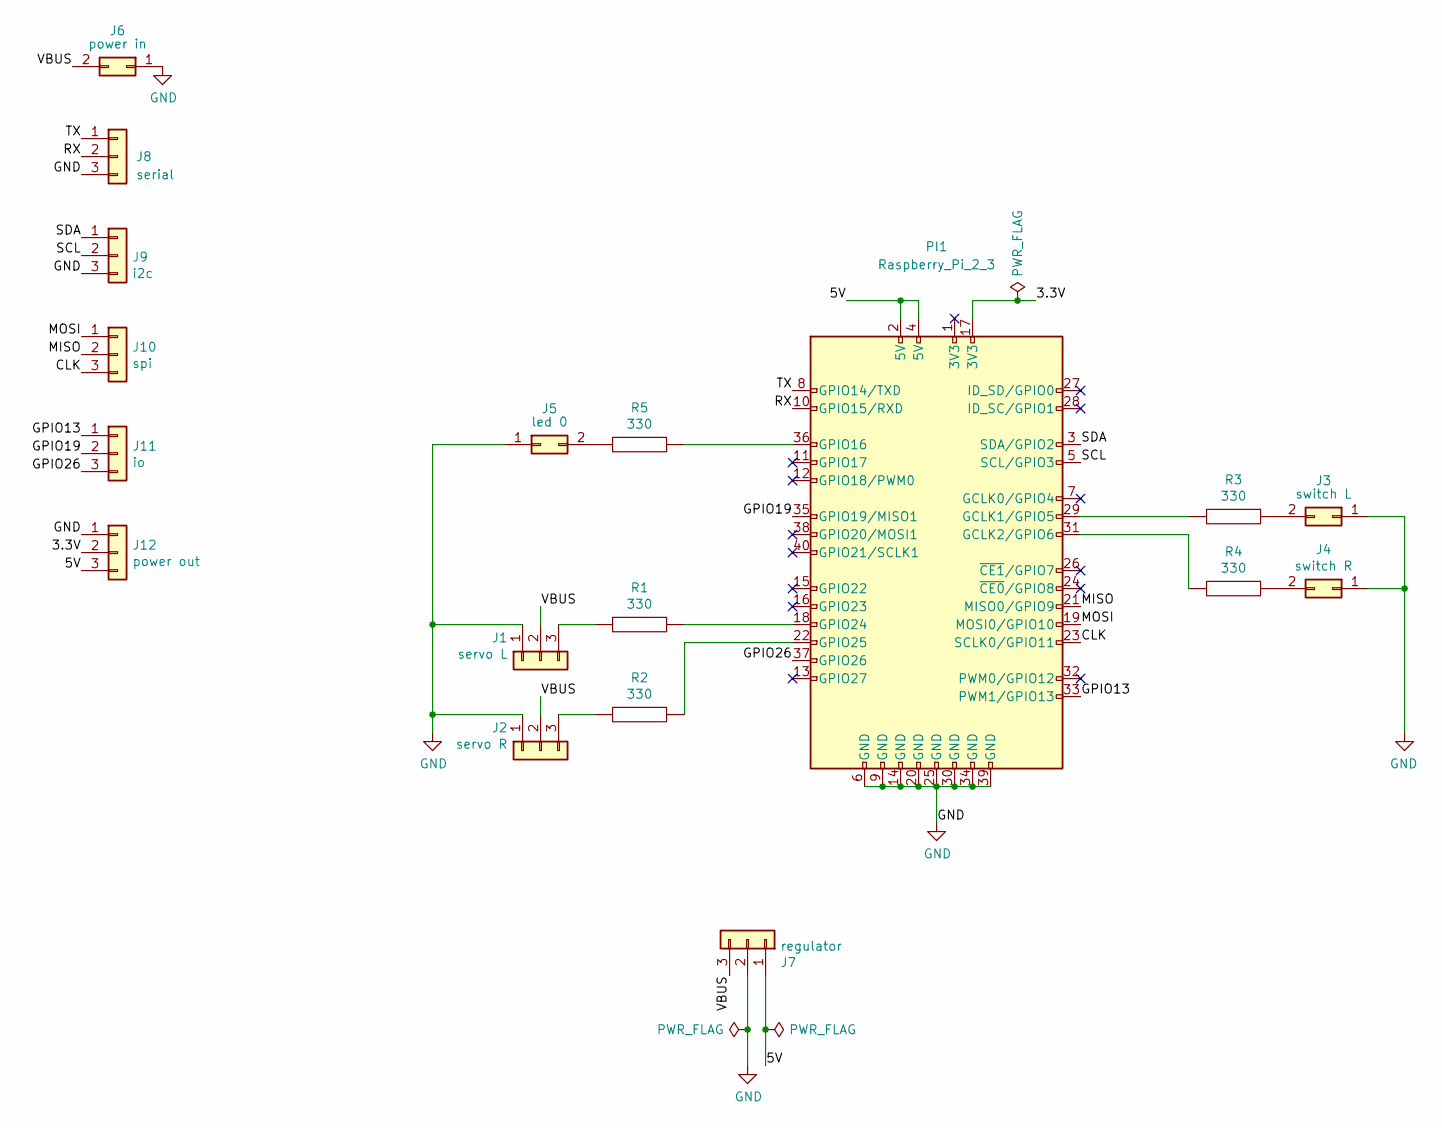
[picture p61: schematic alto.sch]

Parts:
J1: servo L; Pin_Header_Straight_1x03_Pitch2.54mm
J2: servo R; Pin_Header_Straight_1x03_Pitch2.54mm
J3: switch L; Pin_Header_Straight_1x02_Pitch2.54mm
J4: switch R; Pin_Header_Straight_1x02_Pitch2.54mm
J5: led 0; LED_D5.0mm
J6: power in; Pin_Header_Straight_1x02_Pitch2.54mm
J7: regulator; Pin_Header_Straight_1x03_Pitch2.54mm
J8: serial; Pin_Header_Straight_1x03_Pitch2.54mm
J9: i2c; Pin_Header_Straight_1x03_Pitch2.54mm
J10: spi; Pin_Header_Straight_1x03_Pitch2.54mm
J11: io; Pin_Header_Straight_1x03_Pitch2.54mm
J12: power out; Pin_Header_Straight_1x03_Pitch2.54mm
PI1: Raspberry_Pi_2_3; Socket_Strip_Straight_2x20_Pitch2.54mm
R1, R2, R3, R4, R5: 330; Resistor_SMD+THTuniversal_0805to1206_RM10_HandSoldering

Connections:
/3.3V: J12.2, PI1.17 (3V3)
/5V: J7.1, J12.3, PI1.2 (5V), PI1.4 (5V)
/CLK: J10.3, PI1.23 (SCLK0/GPIO11)
/GPIO13: J11.1, PI1.33 (PWM1/GPIO13)
/GPIO19: J11.2, PI1.35 (GPIO19/MISO1)
/GPIO26: J11.3, PI1.37 (GPIO26)
/MISO: J10.2, PI1.21 (MISO0/GPIO9)
/MOSI: J10.1, PI1.19 (MOSI0/GPIO10)
/RX: J8.2, PI1.10 (GPIO15/RXD)
/SCL: J9.2, PI1.5 (SCL/GPIO3)
/SDA: J9.1, PI1.3 (SDA/GPIO2)
/TX: J8.1, PI1.8 (GPIO14/TXD)
/VBUS: J1.2, J2.2, J6.2, J7.3
GND: J1.1, J2.1, J3.1, J4.1, J5.1, J6.1, J7.2, J8.3, J9.3, J12.1, PI1.6 (GND), PI1.9 (GND), PI1.14 (GND), PI1.20 (GND), PI1.25 (GND), PI1.30 (GND), PI1.34 (GND), PI1.39 (GND)
unnamed: J1.3, R1.1
unnamed: J2.3, R2.1
unnamed: J3.2, R3.1
unnamed: J4.2, R4.1
unnamed: J5.2, R5.1
unnamed: PI1.18 (GPIO24), R1.2
unnamed: PI1.22 (GPIO25), R2.2
unnamed: PI1.29 (GCLK1/GPIO5), R3.2
unnamed: PI1.31 (GCLK2/GPIO6), R4.2
unnamed: PI1.36 (GPIO16), R5.2

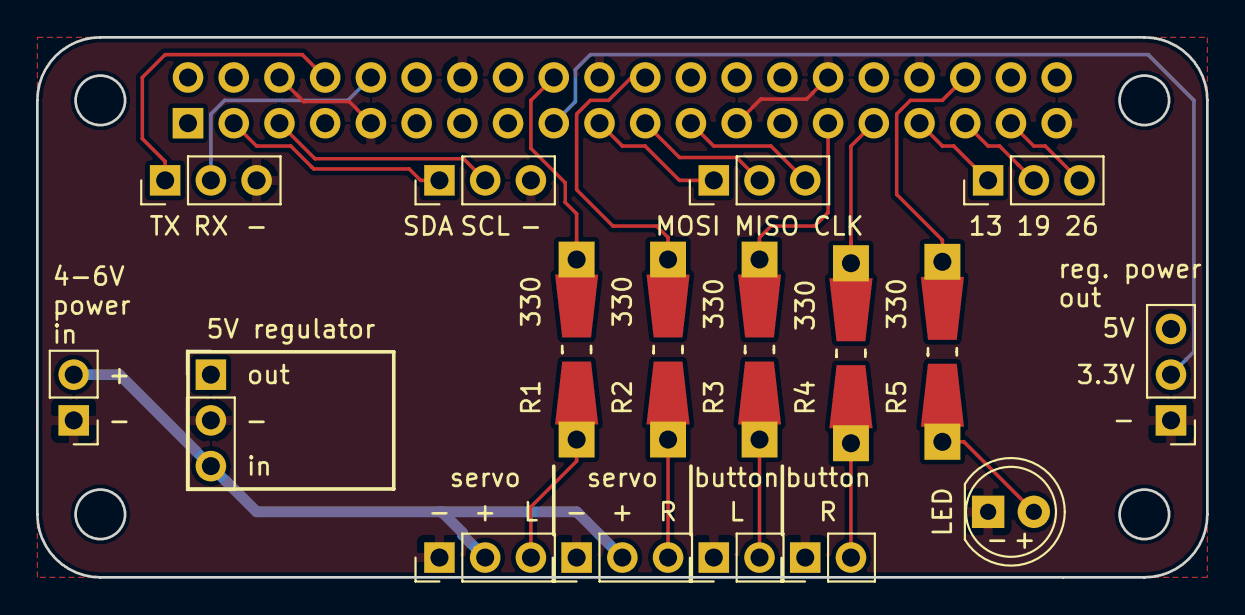
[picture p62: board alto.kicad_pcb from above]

Board: 2 copper layers, 65.0 x 30.0 mm, 18 parts (1 on the bottom side), 24 nets.

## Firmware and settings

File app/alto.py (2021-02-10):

# Copyright 2021 Google LLC

# Licensed under the Apache License, Version 2.0 (the "License");
# you may not use this file except in compliance with the License.
# You may obtain a copy of the License at

#     https://www.apache.org/licenses/LICENSE-2.0

# Unless required by applicable law or agreed to in writing, software
# distributed under the License is distributed on an "AS IS" BASIS,
# WITHOUT WARRANTIES OR CONDITIONS OF ANY KIND, either express or implied.
# See the License for the specific language governing permissions and
# limitations under the License.

import argparse
import logging
import queue
import time

import RPi.GPIO as GPIO
import picamera
import pigpio

from button_handler import ButtonHandler
import imprint_engine
import servo_handler
import task
import ui


# Configuration for all the pins. The pin numbering used is BCM.
BUTTON_PINS = [5, 6]
LED_PIN = 16

# Servos are controlled by periodically sending a pulse. The length
# of the pulse sets the position. Typically servos accept a pulse length
# between 1ms and 2ms, although most can go beyond these limits to provide
# an increased range of motion.
# WARNING: changing the pulse lengths below 1ms or above 2ms may cause damage
# to a servo - please experiment carefully.
SERVO_CFG = [
        # The left hand servo is configured as a mirror image (start and
        # stop are switched around).
        dict(pin=24, start_pulse=0.00185, end_pulse=0.00115),
        # The right hand servo is configured normally.
        dict(pin=25, start_pulse=0.00115, end_pulse=0.00185),
]

# The minimum confidence to accept when classifying.
# This value must be between 0 and 1. A smaller value makes the system more
# likely to match any label, resulting in greater sensitivity.
CONFIDENCE = 0.8

# The classifying results are passed through a filter to produce more stable
# results.
# This value adjusts how quickly the unit responds to changes while
# classifying.
# This value must be between 0 and 1.
RESPONSIVENESS = 0.2


def set_up_led(bus, pin):
    '''Sets up the status LED.

    Args:
      bus: The message bus to bind to.
      pin: The GPIO pin to use.

    Returns:
      A set function to directly set the LED.

    Binds to:
        Output.set_led(value: float)

    Uses RPi.GPIO rather than pigpio so that an error can be displayed
    if the pigpio daemon is not running.
    '''
    GPIO.setup(pin, GPIO.OUT)

    def set(value):
        GPIO.output(pin, value >= 0.5)

    bus.bind('Output.set_led', set)
    return set


def set_up_buttons(bus, pins):
    '''Sets up the input buttons.

    Args:
      bus: The message bus to bind to.
      pins: A list of GPIO pins to use.

    Emits:
      Input.button_changed(index: int, pressed: bool)

    Uses pigpiod to provide debouncing.
    '''
    pi = pigpio.pi()
    if not pi.connected:
        raise RuntimeError('Pigpio failed to connect to the daemon')

    # Set up each pin with a pullup and a 500us glitch filter
    # for debouncing.
    for pin in pins:
        pi.set_mode(pin, pigpio.INPUT)
        pi.set_pull_up_down(pin, pigpio.PUD_UP)
        pi.set_glitch_filter(pin, 500)

    # Wait for the pins to settle.
    time.sleep(0.01)

    # Set up a callback to handle press/release events.
    def on_change(gpio, level, tick):
        idx = pins.index(gpio)
        bus.emit('Input.button_changed', idx, level == 0)

    for pin in pins:
        pi.callback(pin, pigpio.EITHER_EDGE, on_change)


def main(confidence=CONFIDENCE, responsiveness=RESPONSIVENESS):
    '''Runs all the tasks required for Alto.

    Uses a TaskManager to start the tasks, check that they are alive
    and as a messaging bus.

    Blinks the LED on any errors.

    Emits:
      System.started()
    '''
    task_manager = task.TaskManager()
    GPIO.setmode(GPIO.BCM)

    # Set up the LED first as it is used if there are any errors.
    set_led = set_up_led(task_manager, LED_PIN)

    try:
        # Start the output tasks first and input tasks last.
        # This should ensure that all the bindings are in place
        # before the inputs are processed.
        task_manager.start(imprint_engine.ImprintEngineTask,
                confidence, responsiveness)
        task_manager.start(servo_handler.ServoHandler, SERVO_CFG)
        task_manager.start(ui.AltoUI)
        task_manager.start(ButtonHandler)
        set_up_buttons(task_manager, BUTTON_PINS)

        # Indicate the system is ready by turning on the LED.
        task_manager.emit('System.started')
        set_led(1)

        # Run forever
        task_manager.process_messages()
    except KeyboardInterrupt:
        pass
    except Exception as exc:
        logging.exception('Error in main')

        # Emit a blink error code
        if isinstance(exc,  picamera.PiCameraError):
            # Camera problems are shown as two blinks.
            blinks = 2
        else:
            # All other problems (most likely the TPU isn't conencted)
            # are shown as three blinks.
            blinks = 3

        set_led(0)
        time.sleep(1)
        # Emit the pattern 10 times.
        for _ in range(10):
            for _ in range(blinks):
                set_led(1)
                time.sleep(0.15)
                set_led(0)
                time.sleep(0.10)
            # Pause between sets.
            time.sleep(0.5)
    finally:
        # Clean up the tasks and turn the LED off on exit.
        task_manager.terminate()
        set_led(0)
        GPIO.cleanup()


if __name__ == "__main__":
    # Parse command line arguments.
    def norm_float(value):
        v = float(value)
        if v < 0 or v > 1:
            raise argparse.ArgumentTypeError(
                    '%s is not in the range of 0-1' % value)
        return v

    parser = argparse.ArgumentParser()
    parser.add_argument("-v", "--verbose", help="increase output verbosity",
                        action="store_true")

    parser.add_argument("--confidence", type=norm_float, default=CONFIDENCE,
            help='''
Sets the minimum confidence to accept when classifying.
This value must be between 0 and 1. A smaller value makes the system more
likely to match any label, resulting in greater sensitivity.''')

    parser.add_argument("--responsiveness", type=norm_float,
            default=RESPONSIVENESS,
            help='''
Sets how quickly the unit responds to changes while classifying.
This value must be between 0 and 1.''')

    args = parser.parse_args()
    if args.verbose:
        logging.basicConfig(level=logging.INFO)

    main(args.confidence, args.responsiveness)

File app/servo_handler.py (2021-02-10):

# Copyright 2021 Google LLC

# Licensed under the Apache License, Version 2.0 (the "License");
# you may not use this file except in compliance with the License.
# You may obtain a copy of the License at

#     https://www.apache.org/licenses/LICENSE-2.0

# Unless required by applicable law or agreed to in writing, software
# distributed under the License is distributed on an "AS IS" BASIS,
# WITHOUT WARRANTIES OR CONDITIONS OF ANY KIND, either express or implied.
# See the License for the specific language governing permissions and
# limitations under the License.

import math
import time

import pigpio

import task


class Servo(object):
    '''Keeps information about a servo.'''

    def __init__(self, pin, offset, scale):
        '''Constructor.

        Args:
          pin: int, the BCM pin number the servo is connected to.
          offset: float, the pulse length in seconds to use at position 0.
          scale: float, the amount to adjust the pulse length as position 1.'''
        self.pin = pin
        self.offset_us = offset * 1000000
        self.scale_us = scale * 1000000
        self.pulse_us = 0

    def set_position(self, value):
        '''Sets pulse_us using the given value.

        Args:
          value: Union[float, None], a normalised (0-1) input value.

        If the value is None then pulse_us is set to 0, which lets a
        servo idle.'''
        if value is None:
            self.pulse_us = 0
        else:
            value = max(0, min(1, value))
            self.pulse_us = int(self.offset_us + self.scale_us*value)


class ServoHandler(task.Task):
    '''Controls a number of servos.

    Binds to:
      Output.set_servo(index: int, value: float)
      Output.sweep_servos(duration: float, sweps: List([int, float, float]))

    Avoids power spikes by interleaving servo movements.
    Avoids jitter by idling after a configurable period of inactivity.
    '''

    # A common servo standard is to send pulses at 50Hz which is every 0.02
    # seconds.
    FRAME_PERIOD_US = 20000

    def __init__(self, task_args, config, drive_time=2):
        '''Constructor.

        Args:
          config: Tuple[Tuple[int, float, float]], the servos to use.
          drive_time: float, the time in seconds to drive the servos for.
        '''
        super().__init__(task_args)
        self.drive_time = drive_time
        self.last_change = time.monotonic()

        # Connect to pigpio.
        self.pi = pigpio.pi()
        if not self.pi.connected:
            raise RuntimeError('Pigpio failed to connect to the daemon')

        # Add all the servos.
        self.servos = []
        for item in config:
            self.add(**item)

        self.bind('Output.set_servo', self.set_servo)
        self.bind('Output.sweep_servos', self.sweep_servos)

    def run(self):
        '''The task's main loop.

        Processes messages and sends pulses.'''
        while self.process_messages(batch=True, block=self._is_idle()):
            if not self._is_idle():
                # Send the pulses to the servos.
                # To reduce CPU usage sends batches of 5 pulses at a time.
                self._send_pulses(self._get_pulses(), 5)

    def add(self, pin, start_pulse=0.001, end_pulse=0.002):
        '''Adds a servo with the supplied config.

        Args:
          pin: int, the BCM pin number the servo is connected to.
          start_pulse: float, the pusle length in seconds at position 0.
          end_pulse: float, the pusle length in seconds at position 1.
        '''
        # Set up the pin.
        self.pi.set_mode(pin, pigpio.OUTPUT)

        # Convert (start, end) to and (offset, scale) for easier maths.
        offset = start_pulse
        scale = end_pulse - start_pulse
        self.servos.append(Servo(pin, offset, scale))

    def set_servo(self, idx, value):
        '''Sets a servos position.

        Args:
          idx: int, the servo index.
          value: float, the position between 0 and 1.'''
        # Update the servo.
        servo = self.servos[idx]
        self.servos[idx].set_position(value)

        # Trigger driving.
        self.last_change = time.monotonic()

    def sweep_servos(self, duration, sweeps):
        '''Sweeps any number of servos in parallel.

        Args:
          duration: float, the time in seconds to sweep over.
          sweeps: List[Sweep], the sweeps to perform.

        Each item in the list of sweeps is a tuple of:
          (idx, start, end)

          idx is the servo index,
          start and end are normalised positions (0-1)
          duration is in seconds.

        This message is blocking.
        '''
        duration_us = duration * 1000000

        # Round up to the next frame period.
        frame_us = self.FRAME_PERIOD_US
        duration_us = int(math.ceil(duration_us/frame_us)*frame_us)

        # Build up a complete set of pulses for the entire duration
        pulses = []
        for us in range(0, duration_us, frame_us):
            norm_pos = us / (duration_us - frame_us)
            for idx, start, end in sweeps:
                self.servos[idx].set_position(start + (end-start) * norm_pos)
            pulses += self._get_pulses()

        # Send the pulses.
        self._send_pulses(pulses)

        # Trigger the idle logic.
        self.last_change = time.monotonic()

    def _is_idle(self):
        '''Returns True if the servos should be idle.'''
        return time.monotonic() > self.last_change + self.drive_time

    def _get_pulses(self):
        '''Gets the list of pulse instructions to send to pigpio.

        The instructions are for one pulse per servo.
        The pulses are interleaved to reduce peak power draw.
        '''
        count = len(self.servos)
        frame_duration = self.FRAME_PERIOD_US // count
        pulses = []
        for servo in self.servos:
            # Handle zero pulse widths specially, otherwise pigpio sends
            # single microsecond signals on the pin.
            if servo.pulse_us:
                # Pulses use a bitwise pin mask rather than a single pin.
                pin_mask = 1 << servo.pin
                pulses += [
                    # Turn on for the pulse time.
                    pigpio.pulse(pin_mask, 0, servo.pulse_us),
                    # Turn off for the rest of the frame.
                    pigpio.pulse(0, pin_mask, frame_duration - servo.pulse_us),
                ]
            else:
                pulses += [
                    # Do nothing for the entire frame.
                    pigpio.pulse(0, 0, frame_duration),
                ]
        return pulses

    def _send_pulses(self, pulses, repeat=1):
        '''Sends a list of pulses a number of times.
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
